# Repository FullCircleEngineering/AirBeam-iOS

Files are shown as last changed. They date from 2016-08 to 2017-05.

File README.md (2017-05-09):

# AirBeam-iOS
This directory contains material for an iOS modified AirBeam.  The build files include revisions to the Eagle PCB layout/circuitry, and revisions to the Arduino firmware code.

1. PCB files original: Airbeam-master
2. PCB files modified: Airbeam-iOS-modifications
3. Firmware files modified: AirBeamFirmware_11_14_15-iOS

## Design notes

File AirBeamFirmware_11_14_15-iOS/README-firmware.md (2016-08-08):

# AirBeam Firmware for iOS modifications

## Original source code
This firmware was modified from the original source code available from AirCastingAndroidClient/arduino/aircasting/AirBeamFirmware_11_14_15.

The original firmware was released under the GNU Affero General Public License v3.

## SDK and dependencies
This code was successfully compiled, uploaded and tested using the Arduino 1.6.5 IDE.  The hardware board equivalent for the AirBeam is the "Leonardo".  You must also copy the "DHT-sensor-library-master" folder to your IDE libary root directory to ensure proper linking with the firmware library dependencies. 

## The RN4020 BTLE module
This firmware was modified to work with the modified AirBeam hardware.  The AirBeam hardware was modified to use the RN4020 BTLE module instead of the current BlueTooth Standard (SPP) module.  The RN4020 is unique in that is does not use a standard BTLE characteristic, rather abstracts on BTLE to create a pseudo-SPP serial interface.  
In other words, you can stream ASCII characters to the RN4020 as you would a BlueTooth Standard (SPP) module, and capture those characters on the other side of your connection as if it were a serial/SPP connection.
The implications: Serial data can be streamed to the RN4020 module just as they are being done currently with the BlueTooth Standard module.  No special communication/configuration is necessary firmware side to accomodate BTLE.
  
## Modifications for iOS
No significant modifications occured for use with iOS other than changing the configuration options in the ```setup(){}``` section to configure the rn4020 using AT commands (refer to the rn4020 user guide).
**The data output has not changed** from the 11/14/15 version of the firmware, accept to stream the data as newline delimited blocks of comma delimited fields (instead of the old version of character-heavy JSON).

#TO DO
The firmware is incomplete as of 08/08/2016.  Additional code needs to be added to the ```setup(){}``` section to capture the RN4020 UID, e.g. AirBeam-04A35T67
This UID needs to be included in each data block export so that the data can be associated with a specific device/UID.

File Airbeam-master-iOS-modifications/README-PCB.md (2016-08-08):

# AirBeam-Hardware(PCB)-iOS

## Original source code
These design files were modified from the original source file available from https://github.com/vitiral/Airbeam.

## Modifications for iOS
MODIFIED: 07/08/2016 Nick Masson nicholas.b.masson@gmail.com

The original source files were modified to remove the old BlueTooth Classic module and replace it with the [RN4020 BTLE module](http://www.microchip.com/wwwproducts/en/RN4020).
The RN4020 takes a 3.3V TX/RX connection akin to the old BTClassic module.  It communicates with it's master via AT commands (reference the user guide).
Unlike other BTLE modules, it does use a standard BTLE profile for sending/receiving data.  It uses the Microchip-specific MLDP profile, which allows for a transparent serial-like connection (essentially a BTClassic connection using SPP).  As such, ASCII data can be streamed to the RN4020 over UART as with the BTClassic SPP method.

The 5-pin header wiring was also modified to remove a GPIO connection and replace it with the V_charger connection.  i.e. you can now use the 5-pin header to charge the LiPo battery with an unregulated 5VDC input (analagous to charging via the USB port).  This allows for more robust connections when integrating the AirBeam in to other control/embedded systems.

## ***IMPORTANT***

#Testing
The revised PCB was printed, populated and tested.  All BTLE functionality was verified and working.  As such, the Gerber Files included here should be verified for production.

#BOM
***NO CHANGES*** have been made to the BOM between the original and modified files directories.  The possition of all components on the board, however, is the exact same as before **accept** the RN4020 module.
The old BOM and pick'n'place possitions should be the same; the only change necessary is repalcing the BTClassic module possition with the possition of the RN4020 module.

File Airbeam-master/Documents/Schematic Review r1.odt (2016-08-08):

Todo:

- Update USB voltage regulator

Hi Fellas-

Garrett, thanks for sending the design files and opening it up to review. I just completed my review of the Rev1 Schematic. I downloaded the files from Github at 9:15a on 3/25, which according to Garrett's email yesterday is the most up to date version.

I completed the following tasks:

1. Reviewed each section of the circuit
2. Verified USB connection scheme to uC
3. Checked crystal selection
4. Checked HWB pin
5. Checked to be sure the board is a good representation of a Leonardo
6. Reviewed supervisor selection and the output polarity.
7. Reviewed switcher selection.
8. Checked capacitor choices for switchers
9. Reviewed P-ch mosfet selection
10. Checked connection to the BT module
11. Checked pinout of ICSP port
12. Checked the LiIon charger chip and Iset resistor
13. Checked sensor connections.
14. Reviewed ESD connections.
15. Reviewed dumb stuff like connections to pins, spot checked pin names, USB pinout,

Here are my suggestions for changes to make (I think you know some of them exist, but I don't want to miss them):

1. LED_BT circuit doesn't have a connection to signal or ground.

Knew about this one, has been connected to Pin 13 as confirmed by Michael.

2. The UBT schematic symbol looks like it is missing an outline. Same for the USB connector.
  Updated – also made the temp sensor and voltage regulators have an outline.
3. Many of the parts have superfluous information still visible which makes the schematic appear cluttered. Example: UBT's pin names like 'P$1' are listed. Same for Con_addon, USB's pin directions, etc...

Good point. Changed.

4. I see you've selected the SOT-23 version of the MCP73831. With 5V in and a dead battery at 2.9V the part will try to charge at 500mA which generates 1W of heat. The SOT-23 part has thermal resistance of 230*C/W, which will result in using the chip's thermal limiting feature, and significantly slow down the charge time. I would suggest changing to the DFN part which has a thermal resistance of 76*C/W, or lower if a large PCB pad is used.

Done as of revision 1_4

5. The 5V IO connections from the uC go directly to the 3.3V BT module IO pins. There needs to be level shifters at least from uC->BT to ensure there is no damage to the pin. I can suggest http://www.digikey.com/product-detail/en/SN74LVC1G125DBVR/296-11603-1-ND/385742

Thankyou and done. I used your part

6. VR_MOS-N1 is listed on the BOM as DNP but it will be needed to control the fan. Also, if the fan is always running when the unit is running is it needed at all? If so, N-channel FETs should be at a lower potential than the load. Finally, I wasn't able to review the part selection since there is no part information on the BOM (I'd suggest leaving part information in the BOM and marking DNP in another field in case you want to quickly change population status).

I will use the Value field from now on. Michael has suggested that he would appreciate this part – and the only overhead is a 0ohm resistor. I will continue with it in the design.

7. Any connection that is accessible to the customer should have ESD protection. I think the CON_ADDON will be user-accessible, so ESD protection should be added. I don't think other connections are accessible, but if they are protection should be added.

Would you recommend just a Varistor (like the Arduinio)? I have added varistors and a ferite bead onto the GND. Let me know if you think this is enough.

8. The uC crystal that you selected may have too high load capacitance. I would suggest one with 10-15pF typ of load capacitance to keep the 32u4 happy. Although if you have the BOM for the leonardo and this is the part that is listed then you should probably keep what works.

The range suggestion is 12-22pF, and I have 20pF. The Leonardo had 22pF caps. I'm using the caps that are suggested with this crystal.

I also checked the page you suggested in the email and responded – the crystal falls within the 10-22pF range specified (table 6.3, page on the uC datasheet (page 30) )

9. You need to add a pullup on the output of the VDETECT supervisor part.

NOTE: The part has changed, but both parts were push/pull. I think you may have made a mistake.

10. I've been thinking about the VDETECT voltage limit, and you may want to find a part that has a slightly higher cutoff. This would be to accommodate the wide temperature range that the battery is forced to operate under. While it will reduce the battery life of the battery, it could increase the number of useful cycles that the battery gets over time. Finding one a 3.0 or 3.1V also wouldn't represent much energy loss because that's the non-linear part of the Li_Ion discharge curve.

I could not find a part from that company on digikey. I found a different companies part. Please review:

http://www.digikey.com/product-detail/en/APX809-31SAG-7/APX809-31SAGDICT-ND/1844722

I have added the part to the schematic

And some questions that may not be problems, but I don't understand them:

1. What is the little drawing of the Arduino in the lower right hand corner of the schematic?

Answered in separate email.

2. Regarding the AREF connection question: no, it does not need to be connected to VCC since the chip has a crappy internal reference of 1/2VCC, VCC, or GND. However you're right to use the capacitor for stability of the self-selected reference.
3. Is there a reason that you're connecting the BT module to IO10 and IO11? I would think that using the hardware UART at D0 and D1 might be easier. However if that is how the current prototype is used, then I'd stick with what works.
4. You have the PS pins of the switchers connected to ground. While this increases efficiency at low load, it also drastically increases the supply ripple in this low power state. Because some of the sensors depend on this voltage rail for accuracy, will this ripple voltage mess up the error budget? At the very least, it is probably a good idea to have a couple 0-ohm jumpers to enable you to change this setting with a population change.

I have added 0 ohm jumpers and selected the 5V switcher to do continuous switching (PS = 1) and the 3.3V to be in power save (PS = 0).

5. How did you determine acceptable ripple of the switcher output for capacitor selection? Since the sensors depend on the 5V regulator for accuracy it is important.

I used the suggested schematic. I rechecked the values, and the calculated max delta V = 0.01 Volts. I also checked it for over 10x our current usage (1A, which isn't even possible for this device), and it is still only .02 Volts. I'd say 20uF is good. This was at a Vmin = 2.9 (higher Vmin only helps us). It is in BOM/Calculations.ods.

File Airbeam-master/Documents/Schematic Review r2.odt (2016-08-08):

Hi Garrett-

Nice layout. Glad that you were able to stick with a 2-layer, 1-sided board. I've completed the review. Below are my notes. Feel free to reach out with any questions or comments, which I'm sure you'll have since many of the PCB layout design decisions are often subjective.

Aspects Reviewed:

1. Reviewed changes suggested from my schematic review.
2. Reviewed the new supervisor circuit
3. Reviewed the new ESD protection
4. Switcher layouts for noise
5. Switcher layouts for heat
6. USB charger for heat, noise
7. Position of Bluetooth module WRT to other components and pours
8. Crystal position
9. Decoupling capacitor positions
10. High current trace widths and return paths
11. Ground design of analog vs. digital vs. power
12. Clearance from PCB edge
13. Reviewed silkscreen: off pads, sufficient size, clarity, polarization marks, pin 1 marks
14. Reviewed soldermask:
15. Reviewed solderpaste
16. Feducial review
17. Run DRC per Laen's specs

Suggestions for changes to make:

1. For U$2, there is not reference designator on the schematic.

Done. I have renamed it to U_VRUSB

2. For U$2, I would suggest using a different copper pour that does not have thermals. This will increase the effectiveness of the thermal pad. Also, I believe that you need a 1sqin copper pour to act as a heatsink in order to reach the thermal resistance listed on the datasheet. I would suggest moving this entire circuit to the right to better take advantage of the available pour, and perhaps move a few traces around to facilitate heat expulsion.

Done. It should be good now!

3. I would flip the position of U-C1 and C2 to place the smaller cap closer to the part.

Done

4. I would move UR_R2 on the PCB to allow better heat conduction of the pour away from the part. Rotating UR_C1 would be helpful.

Done. Also, caps were rotated.

5. The trace going from Vout to VR3_R1 should connect to the output node further away from the switcher than the output capacitors for stability. Rerouting this trace will also allows you to more directly connect the ground pins of the output capacitors to the ground plane (a must), and increase the size of the thermal pad for the part (not really needed since the power consumption of this part is low).

I moved it to increase pad area and it is now coming out at the pad of the cap. This is going to have to be good enough.

6. The via coming off of VR3_R1 on the 3.3V side goes nowhere and should be removed.

Removed, thanks for noticing.

7. on U_VR3 and U_VR5 I think pins 7 and 9 are flipped on your footprint. Pin 7 should be PS, 9 should be GND.

Oh my god, I had the pin numbers totally flipped on the right side. Updated, with that whole section re-designed around the new pins and your suggestions.

8. You seem to have a couple vias going nowhere at (35,25) and (35, 28)

Thanks, they were meant to be GND vias, but then the Voltage bus went under them.

9. VR5_C2 and C3 need to have their ground traces connect directly to U_VR5's ground pin. I would suggest moving the +5V trace that is blocking it around the back side of the capacitors, which is should do anyway to give the smoothest output.

Yes, I suppose connecting directly to the GND is best. Done.

10. All copper traces and pours should be kept away from the area of the BT module that has the antenna to prevent signal attenuation. I would pull back the pours as much as possible, but at least back to where the SMT pins of the parts are and as far down the board as possible. See page 25 of the BT module datasheet.

Absolutely. I looked at the data sheet and created a 15mm restrict area (per their design). Thanks for catching this.

11. I'm not sure if it is possible, but UC_C1 and C2 should be moved closer to the uC. Decoupling capacitors are more effective when their output doesn't have to flow through 2 vias. I would rate this as non-critical.

I moved one of the caps (to a different Vin pin I hadn't seen before) and altered the design as you suggested.

12. I would add a decoupling cap to the U_BT_RX part. Also, those level shifters don't have their reference designators visible on the schematic.

The RX component already shared a 1uF cap with the BT module itself. However, I added a 100nF cap to the TX part (5V). Added reference designators.

13. I would add decoupling capacitors on all sensor power pins, including the CON_ADDON connector.

Done. I skipped the 3.3V because there is no room and it is right next to the power supply (and therefore 20uF of caps).

14. Silkscreen problems:

General comment: silkscreen on the pads is because these parts/pads are from libraries. I have used them for a long time and they have always worked well. I don't know why they put SS on the pads, but it works.

  1. R_LED_CH (no polarity, overlap on other silk)

It is a resistor, silkscreen is intended.

  1. U_FB2

silkscreen intended.

  1. U_FB1 (name not there, some silk on the pad)

fixed the name, silkscreen intended

  1. U_VR5
  1. I don't think you have pin1 indicators on any of the ICs. Please add them and be sure that they are visible after the part has been populated.

I added pin indicators for all parts. Thanks.

  1. Vdetect has silk on the pads

These are on purpose.

  1. FAN_MOS_N1, VR_MOS-P1, CON_FAN, BT module, UC_F1, U_VR3, V_VR5, CONN_ADDON has silk on the pads

This has never been a big deal for me (and is actually designed in on purpose for the resistors, capacitors, mosfets, and ferrite beads).

  1. CON_ADDON has no silk name

fixed

Questions and comments that may not be problems:

1. Regarding the ESD protection, I think Varistors selected are sufficient.

Good, thanks for reviewing.

2. There are a few vias that appear to be randomly placed throughout that I don't understand. (4,32), (6, 27), (12, 30) (54, 5). Are they there to connect the two planes? If so, this should be done with 1 via, or if multiple are needed then they should be closer together to prevent ground loops.

I have read a large number of accounts that say that by throwing Vias all over the place (at random places) you will prevent ground loops. That is the intent here. I actually added even more vias to the GND plane in various spots.

3. Be mindful of the ground return path for things, especially high current and switched current paths. It looks ok for now but a 2-layer one sided design is susceptible to having ridiculous ground paths which generate noise and measurement anomalies.

Thanks, will do. I think the fan and the Dust sensor are definitely the most suceptible to this. What would you do? I assume caps are the best defense.

4. It seems that there are many TH components. I'm not sure if that is a design decision, but it'll cost more to manufacture TH components.

It was a design decision made by Michael and Chris – and I actually forgot the major price difference for TH. Most of them were chosen because they have better structural reliability, but the connectors to the fan and dust sensor could have definitely been SMT.

5. Did you include the Mask and Silk layers when running DRC? I think you may have found a bunch of the above errors.

I ignored the silkscreen error checking, so I forgot to check the values layer. This time I went through it step by step and approved them.

Next Steps:

1. Once you generate the gerbers, please send them over to me to review them on the most basic level.

They are included in the folder “Gerber”

2. I did not review the mechanical aspects of the design. Perhaps Chris would be better suited for that thanks to the use of DXFs?

Yes, I think so.

3. With the board complete, don't forget to create a paper printout and double check footprints. I would include things like mounting hardware in this review.There is a weird setting in Eagle to do this. Instructions: http://bit.ly/1gVq6sA

I have printed this out as Airbeamv0_01.pdf

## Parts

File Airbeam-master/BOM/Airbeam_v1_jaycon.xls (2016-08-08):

Qty-1 | Part References | Value | Package | Mfg Part Num | Mfg Name | Description | Value | Pkg Code | VID | Vendor Part Num | Price @20 | Price @ 500 | Height | Link | XREF
1 | VR_R4 | 0 | 0603-RES | RC0603JR-070RL | Yageo | Resistor | 0 | 603 | * | 311-0.0GRCT-ND | 0.0045 | 0.00294 | * | http://www.digikey.com/product-detail/en/RC0603JR-070RL/311-0.0GRCT-ND/729622 | REF51
2 | VR3_0R1, VR5_0R2 | 0 | 0603-RES | RC0603JR-070RL | Yageo | Resistor | 0 | 603 | * | 311-0.0GRCT-ND | 0.0045 | 0.00294 | * | http://www.digikey.com/product-detail/en/RC0603JR-070RL/311-0.0GRCT-ND/729622 | REF51
2 | R_LED_BT, R_LED_CH | 1.4k | 0603-RES | RC0603FR-071K4L | Yageo | Resistor | 1.4k | 603 | * | 311-1.40KHRCT-ND | 0.0108 | 0.00364 | * | http://www.digikey.com/product-detail/en/RC0603FR-071K4L/311-1.40KHRCT-ND/729808 | REF53
1 | UC_R1 | 1M | 0603-RES | RC0603FR-071ML | Yageo | Resistor | 1M | 603 | * | 311-1.00MHRCT-ND | 0.015 | 0.00364 | * | http://www.digikey.com/product-detail/en/RC0603FR-071ML/311-1.00MHRCT-ND/729791 | REF60
7 | BT_C1, CD_C1, CE_C1, CTH_C1, UC_C5, UC_C7, UC_C8 | 1uF | 0603-CAP | C1608X5R1C105K080AA | TDK | Capacitor | 1uF | 603 | * | 445-1416-1-ND | 0.0337 | 0.02356 | * | http://www.digikey.com/product-detail/en/C1608X5R1C105K080AA/445-1416-1-ND/569082 | REF46
1 | VR3_L1 | 2.2uH | 1210 | BRL3225T2R2M | Taiyo Yuden | Inductor 2.2uH | 2.2uH | 1210 | * | 587-2165-1-ND | 0.196 | 0.13476 | * | http://www.digikey.com/product-detail/en/BRL3225T2R2M/587-2165-1-ND/2002863 | REF29
1 | VR5_L1 | 4.7uH | 1210 | CBC3225T4R7MR | Richtek USA | Voltage Reg Buck-Boost | * | * | * | 1028-1260-1-ND | 0.8388 | 0.57076 | * | http://www.digikey.com/product-detail/en/RT6150BGQW/1028-1260-1-ND/4733184 | REF26
1 | UC_NTC | 10k | 402 | ERT-J0EM103J | Panasonic | Thermister ? NTC | 10k | 603 | * | P12985CT-ND | 0.143 | 0.07 | * | http://www.digikey.com/product-detail/en/ERT-J0EM103J/P12985CT-ND/761196 | REF41
4 | CTH_R1, UC_R2, UC_R4, UC_R6 | 10k | 0603-RES | RC0603JR-0710KL | Yageo | Resistor | 10k | 603 | * | 311-10KGRCT-ND | 0.008 | 0.00364 | * | http://www.digikey.com/product-detail/en/RC0603JR-0710KL/311-10KGRCT-ND/729647 | REF56
8 | UR_C1, UR_C2, VR3_C1, VR3_C2, VR3_C3, VR5_C1, VR5_C2, VR5_C3 | 10uF | 805 | C2012X5R1C106K085AC | TDK | Capacitor | 10uF | 805 | * | 445-7644-1-ND | 0.1102 | 0.07298 | * | http://www.digikey.com/product-detail/en/C2012X5R1C106K085AC/445-7644-1-ND/2733716 | REF47
1 | U_C3 | 10uF/50V | 1206 | CL31A106KBHNNNE | Samsung | Capacitor ? 50V | 10uF / 50V | 1206 | * | 1276-2876-1-ND | 0.332 | 0.12082 | * | http://www.digikey.com/product-detail/en/CL31A106KBHNNNE/1276-2876-1-ND/3890962 | REF48
1 | UC_CRYSTAL | 16MHz | HC49UP | ECS-160-20-3X-TR | ECS | Crystal | 16MHz | * | * | XC1776CT-ND | 0.455 | 0.266 | 2.3 | http://www.digikey.com/product-detail/en/ECS-160-20-3X-TR/XC1776CT-ND/2676640 | REF5
2 | UC_C3, UC_C4 | 20pF | 0603-CAP | CL10C200JB8NNNC | Samsung | Capacitor | 20pF | 603 | * | 1276-1187-1-ND | 0.0212 | 0.00966 | * | http://www.digikey.com/product-detail/en/CL10C200JB8NNNC/1276-1187-1-ND/3889273 | REF43
2 | U_R1, U_R2 | 22 | 0603-RES | RC0603JR-0722RL | Yageo | Resistor | 22 | 603 | * | 311-22GRCT-ND | 0.008 | 0.00278 | * | http://www.digikey.com/product-detail/en/RC0603JR-0722RL/311-22GRCT-ND/729690 | REF52
1 | VR5_R2 | 53.6k | 0603-RES | RC0805FR-0753K6L | Yageo | Resistor | 53.6k | 603 | * | 311-53.6KCRCT-ND | 0.021 | 0.00364 | * | http://www.digikey.com/product-detail/en/RC0805FR-0753K6L/311-53.6KCRCT-ND/730972 | REF57
3 | VR3_R2, VR3_R4, VR3_R5 | 86.6k | 0603-RES | ERJ-3EKF8662V | Panasonic | Resistor | 86.6k | 603 | * | P86.6KHCT-ND | 0.015 | 0.00624 | * | http://www.digikey.com/product-detail/en/ERJ-3EKF8662V/P86.6KHCT-ND/198534 | REF58
2 | UC_C1, UC_C2 | 100n | 0603-CAP | C1608X7R1E104K080AA | TDK | Capacitor | 100nF | 603 | * | 445-1316-1-ND | 0.011 | 0.0077 | * | http://www.digikey.com/product-detail/en/C1608X7R1E104K080AA/445-1316-1-ND/567697 | REF44
4 | BT_C2, UC_C6, U_C1, VR5_C4 | 100nF | 0603-CAP | C1608X7R1E104K080AA | TDK | Capacitor | 100nF | 603 | * | 445-1316-1-ND | 0.011 | 0.0077 | * | http://www.digikey.com/product-detail/en/C1608X7R1E104K080AA/445-1316-1-ND/567697 | REF44
1 | U_C4 | 100nF | 0603-CAP | CC0603ZRY5V9BB104 | Yageo | Capacitor ? 50V | 100nF / 50V | 603 | * | 311-1343-1-ND | 0.017 | 0.00546 | * | http://www.digikey.com/product-detail/en/CC0603ZRY5V9BB104/311-1343-1-ND/2103127 | REF45
3 | VR3_R1, VR5_R1, VR_R2 | 487k | 0603-RES | ERJ-3EKF4873V | Panasonic | Resistor | 487k | 603 | * | P487KHCT-ND | 0.015 | 0.00624 | * | http://www.digikey.com/product-detail/en/ERJ-3EKF4873V/P487KHCT-ND/198411 | REF59
1 | ATMEGA32U4-T | DNP | TQFP44-PAD | ATMEGA32U4-AU | Atmel | Microcontroller | DNP | * | * | 556-ATMEGA32U4-AU | * | 3.51 | * | http://www.mouser.com/ProductDetail/Atmel/ATMEGA32U4-AU/?qs=sGAEpiMZZMvAvBNgSS9Lqh1wBIpnYT9c | REF1
1 | UBT | BT-NVC-MDCS42A | BT_NVC-MDCS42A | NVC-MDCS42A | iNova | BT Module | * | * | * | n/a | 0 | * | * | n/a | REF8
6 | U_Z1, U_Z2, U_Z3, U_Z4, U_Z5, U_Z6 | CG0603MLC-05E | CT/CN0603 | CG0603MLC-05E | Bourns Inc. | Varistor | * | * | * | CG0603MLC-05ECT-ND | 0.1472 | 0.1092 | * | http://www.digikey.com/product-detail/en/CG0603MLC-05E/CG0603MLC-05ECT-ND/3438061 | REF39
1 | CON_BAT | CON_BAT | JST-2-SMD | S2B-PH-SM4-TB(LF)(SN) | JST Sales America | Conn Battery | * | * | * | 455-1749-1-ND | 0.521 | 0.34734 | * | http://www.digikey.com/product-detail/en/S2B-PH-SM4-TB(LF)(SN)/455-1749-1-ND/926846 | REF25
1 | CON_DUST | CON_DUST | S4B-EH | S4B-EH | JST Sales America | Connector (Dust Sensor) | * | * | * | 455-1627-ND | 0.169 | 0.09906 | * | http://www.digikey.com/product-detail/en/S4B-EH(LF)(SN)/455-1627-ND/926535 | REF17
1 | U_MEGA32U-Q | ATMEGA32U4-MU | QFN44ML7X7 | ATMEGA32U4-MU | Atmel | Microcontroller | 16MHz | * | * | ATMEGA32U4RC-MU-ND | 5.741 | 3.95492 | * | http://www.digikey.com/product-search/en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 | REF2
1 | U_FANM | DNP | SOT23 | NDS331N | Fairchild | MOSFET ? N | * | * | * | NDS331NCT-ND | 0.362 | 0.1407 | * | http://www.digikey.com/product-detail/en/NDS331N/NDS331NCT-ND/458997 | REF62
3 | UC_R3, VR3_0R2, VR5_0R1 | DNP | 0603-RES | RC0603JR-070RL | Yageo | Resistor | 0 | 603 | * | 311-0.0GRCT-ND | 0.0045 | 0.00294 | * | http://www.digikey.com/product-detail/en/RC0603JR-070RL/311-0.0GRCT-ND/729622 | REF51
1 | VR_C1 | DNP | 2917_CAP | T491D107K010AT | Kernet | Capacitor ? Tantilum | 100uF | 2917 | * | * | * | * | * | http://www.digikey.com/product-detail/en/T491D107K010AT/399-3769-1-ND/819094 | REF49
1 | RESET_SWITCH | DNP | SWITCH_TACTILE | TL3315NF250Q | E-Switch | Switch | * | * | * | EG4622CT-ND | 0.185 | 0.14674 | * | http://www.digikey.com/product-detail/en/TL3315NF250Q/EG4622CT-ND/1870402 | REF3
4 | CA_FB1, U_FB1, U_FB2, U_FB3 | FERITE_BEAD | U_FB1 | MH2029-600Y | Bourns Inc. | Ferite Bead | 3A | * | * | MH2029-600YCT-ND | 0.0476 | 0.02324 | * | http://www.digikey.com/scripts/DkSearch/dksus.dll?Detail&itemSeq=147728399&uq=635324759172303876 | REF38
3 | FID1, FID2, FID3 | FIDUCIALMOUNT | FIDUCIA-MOUNT | DNP | DO NOT POPULATE | DO NOT POPULATE | * | * | * | * | * | * | * | DO NOT POPULATE | REF63
1 | CON_ICSP | ICSP | 2X03 | 67997-206HLF | FCI | Connector ISP | * | * | * | 609-3234-ND | 0.292 | 0.17494 | * | http://www.digikey.com/product-detail/en/67997-206HLF/609-3234-ND/1878491 | REF4
1 | LED_BT | LED | LED_550 | 550-1107F | Dialight | LED - Red | Red | * | * | 350-1620-ND | 0.995 | 0.5202 | * | http://www.digikey.com/product-detail/en/550-1107F/350-1620-ND/809018 | REF7
1 | LED_CH | LED | LED_550 | 550-1307F | Dialight | LED ? Green | Green | * | * | 350-1627-ND | 1.09 | 0.5712 | * | http://www.digikey.com/product-detail/en/550-1307F/350-1627-ND/809025 | REF6
1 | LION_BATTERY | OFF_BOARD | EMPTY | 585460_2000MAH | UnionFortune | Battery ? Lion | 2000mAh | * | * | * | 12.55 | 11.16 | * | http://www.jayconsystems.com/3-7-volt-rechargeable-lithium-battery-2000-mah.html | REF24
1 | 3_3V_FAN_COPOL | OFF_BOARD | EMPTY | F16FB-05LLC/E | Copol | Fan Copol | * | * | * | 563-1106-ND | 10.11 | 6.46552 | * | http://www.digikey.com/product-detail/en/F16EA-03LLC%20%2FE/563-1106-ND/1165500 | REF13
1 | DUST_SENSOR | OFF_BOARD | EMPTY | PPD60PV-T2 | SHINYEI | Sensor Dust | * | * | * | * | 0 | 25 | * | n/a | REF12
1 | U_PUSHB | PUSHBUTTON | PUSHBUTTON | LC2259EENP | E-Switch | Power Button | * | * | * | * | 0.655 | 0.535 | * | http://www.futureelectronics.com/en/Technologies/Product.aspx?ProductID=LC2259EENPESWITCH6265227&IM=0 | REF23
1 | U_TEMP-HUM | RHT03 | RHT03 | RHT03 | Maxdetect | Sensor Temp-Humidity | * | * | * | * | 8.96 | 7.96 | * | https://www.sparkfun.com/products/10167 | REF11
1 | CON_FAN | SUR_2PIN | JST-0.8MM | SM02B-SURS-TF | SUR | Connector Fan | 2 pin | * | * | 455-2039-1-ND | 0.581 | 0.4066 | * | http://www.digikey.com/product-detail/en/SM02B-SURS-TF(LF)(SN)%3B/455-2039-1-ND/1634927 | REF15
1 | CON_EXTERN | TBLOCK_5 | TBLOCK_5 | 1770911 | Phoenix | Connector (addon board) | 5 pin | * | DK | 277-2082-1-ND | 0.869 | 0.77 | * | http://www.digikey.com/product-detail/en/1770911/277-2082-1-ND/2192492 | REF19
1 | U_USB_CH | USB-BATTERY_LOAD | TDFN33-14 | AAT3672IWO-4.2-1-T1 | Skyworks Solutions | USB ? Battery + Load | 4.2V | * | * | 863-1545-1-ND | 1.06 | 0.88 | * | http://www.digikey.com/product-detail/en/AAT3672IWO-4.2-1-T1/863-1545-1-ND/4753079 | REF28
1 | CON_USB | USB-FCI | USB-FCI | 10103594-0001LF | FCI | Connector USB Micro | * | * | * | 609-4050-1-ND | 0.678 | 0.45232 | * | http://www.digikey.com/product-detail/en/10103594-0001LF/609-4050-1-ND/2350357 | REF21
2 | U_VR3, U_VR5 | VREG-RTEC6150 | WFDFN-10 | RT6150BGQW | Richtek USA | Voltage Reg Buck-Boost | * | * | * | 1028-1260-1-ND | 0.8388 | 0.57076 | * | http://www.digikey.com/product-detail/en/RT6150BGQW/1028-1260-1-ND/4733184 | REF26
2 | U_BT_RX, U_BT_TX | V_BUFFER | SOT23-5 | SN74LVC1G125DBVR | Texas Instruments | Voltage Buffer | <5 | SOT23-5 | * | 296-11603-1-ND | 0.266 | 0.1482 | * | http://www.digikey.com/product-detail/en/SN74LVC1G125DBVR/296-11603-1-ND/385742 | REF9

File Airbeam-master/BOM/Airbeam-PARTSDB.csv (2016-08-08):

Mfg Part Num | Mfg Name | Description | Value | Pkg Code | VID | Vendor Part Num | Price @20 | Price @ 500 | Height | Link
ATMEGA32U4-AU | Atmel | Microcontroller | 16MHz |  |  | 556-ATMEGA32U4-AU |  | 3.51 |  | http://www.mouser.com/ProductDetail/Atmel/ATMEGA32U4-AU/?qs=sGAEpiMZZMvAvBNgSS9Lqh1wBIpnYT9c
ATMEGA32U4-MU | Atmel | Microcontroller | 16MHz |  |  | ATMEGA32U4RC-MU-ND | 5.741 | 3.95492 |  | http://www.digikey.com/product-search/en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
TL3315NF250Q | E-Switch | Switch |  |  |  | EG4622CT-ND | 0.185 | 0.14674 |  | http://www.digikey.com/product-detail/en/TL3315NF250Q/EG4622CT-ND/1870402
67997-206HLF | FCI | Connector ISP |  |  |  | 609-3234-ND | 0.292 | 0.17494 |  | http://www.digikey.com/product-detail/en/67997-206HLF/609-3234-ND/1878491
ECS-160-20-3X-TR | ECS | Crystal | 16MHz |  |  | XC1776CT-ND | 0.455 | 0.266 | 2.3 | http://www.digikey.com/product-detail/en/ECS-160-20-3X-TR/XC1776CT-ND/2676640
550-1307F | Dialight | LED – Green | Green |  |  | 350-1627-ND | 1.09 | 0.5712 |  | http://www.digikey.com/product-detail/en/550-1307F/350-1627-ND/809025
550-1107F | Dialight | LED - Red | Red |  |  | 350-1620-ND | 0.995 | 0.5202 |  | http://www.digikey.com/product-detail/en/550-1107F/350-1620-ND/809018
NVC-MDCS42A | iNova | BT Module |  |  |  | n/a | 0 |  |  | n/a
SN74LVC1G125DBVR | Texas Instruments | Voltage Buffer | <5 | SOT23-5 |  | 296-11603-1-ND | 0.266 | 0.1482 |  | http://www.digikey.com/product-detail/en/SN74LVC1G125DBVR/296-11603-1-ND/385742
RHT03 | Maxdetect | Sensor Temp-Humidity |  |  |  |  | 6.55 | 6.55 |  | http://www.ebay.com/itm/NEW-DHT22-AM2302-Digital-Temperature-Humidity-Sensor-Replace-SHT11-SHT15-Logger-/271175728425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
PPD60PV-T2 | SHINYEI | Sensor Dust |  |  |  |  | 0 | 25 |  | n/a
F16FB-05LLC/E | Copol | Fan Copol |  |  |  | 563-1106-ND | 10.11 | 6.46552 |  | http://www.digikey.com/product-detail/en/F16EA-03LLC%20%2FE/563-1106-ND/1165500
22-05-7025 | Molex | Connector Fan | 2 pin |  |  | 538-22-05-7025 |  | 0.347 |  | http://www.mouser.com/ProductDetail/Molex/22-05-7025/?qs=xrDmMQn67Z5jplgrvRQ%20IpQ==
SM02B-SURS-TF | SUR | Connector Fan | 2 pin |  |  | 455-2039-1-ND | 0.581 | 0.4066 |  | http://www.digikey.com/product-detail/en/SM02B-SURS-TF(LF)(SN)%3B/455-2039-1-ND/1634927
02SUR-32S | JST Sales America | Connector Fan (wire) |  |  |  | 455-2176-ND | 0.481 |  |  | http://www.digikey.com/scripts/DkSearch/dksus.dll?Detail&itemSeq=147727180&uq=635324752046867637
S4B-EH | JST Sales America | Connector (Dust Sensor) |  |  |  | 455-1627-ND | 0.169 | 0.09906 |  | http://www.digikey.com/product-detail/en/S4B-EH(LF)(SN)/455-1627-ND/926535
1770911 | Phoenix | Connector (addon board) | 5 pin |  | DK | 277-2082-1-ND | 0.869 | 0.77 |  | http://www.digikey.com/product-search/en?x=0&y=0&lang=en&site=us&KeyWords=3M9368-ND
10103594-0001LF | FCI | Connector USB Micro |  |  |  | 609-4050-1-ND | 0.678 | 0.45232 |  | http://www.digikey.com/product-detail/en/10103594-0001LF/609-4050-1-ND/2350357
AP2161DM8G-13 | Diodes Incorporated | USB Overcurrent protection |  | 8-TSSOP, 8-MSOP |  | AP2161DM8G-13DICT-ND |  | 0.2413 |  | http://www.digikey.com/product-detail/en/AP2161DM8G-13/AP2161DM8G-13DICT-ND/3720121
LC2259EENP | E-Switch | Power Button |  |  |  |  | 0.655 | 0.535 |  | http://www.futureelectronics.com/en/Technologies/Product.aspx?ProductID=LC2259EENPESWITCH6265227&IM=0
585460_2000MAH | UnionFortune | Battery – Lion | 2000mAh |  |  |  | 12.55 | 11.16 |  | http://www.jayconsystems.com/3-7-volt-rechargeable-lithium-battery-2000-mah.html
S2B-PH-SM4-TB(LF)(SN) | JST Sales America | Conn Battery |  |  |  | 455-1749-1-ND | 0.521 | 0.34734 |  | http://www.digikey.com/product-detail/en/S2B-PH-SM4-TB(LF)(SN)/455-1749-1-ND/926846
RT6150BGQW | Richtek USA | Voltage Reg Buck-Boost |  |  |  | 1028-1260-1-ND | 0.8388 | 0.57076 |  | http://www.digikey.com/product-detail/en/RT6150BGQW/1028-1260-1-ND/4733184
MC34673AEPR2 | Freescale Semiconductor | Voltage Reg USB |  |  |  | MC34673AEPR2CT-ND |  | 0.7 |  | http://www.digikey.com/product-detail/en/MC34673AEPR2/MC34673AEPR2CT-ND/1867915
AAT3672IWO-4.2-1-T1 | Skyworks Solutions | USB – Battery + Load | 4.2V |  |  | 863-1545-1-ND | 1.06 | 0.88 |  | http://www.digikey.com/product-detail/en/AAT3672IWO-4.2-1-T1/863-1545-1-ND/4753079
BRL3225T2R2M | Taiyo Yuden | Inductor 2.2uH | 2.2uH | 1210 |  | 587-2165-1-ND | 0.196 | 0.13476 |  | http://www.digikey.com/product-detail/en/BRL3225T2R2M/587-2165-1-ND/2002863
CBC3225T4R7MR | Taiyo Yuden | Inductor 4.7uH | 6uH | 1210 |  | 587-1624-1-ND | 0.212 | 0.12 |  | http://www.digikey.com/product-detail/en/CBC3225T4R7MR/587-1624-1-ND/1008239
RT9819C-26GV | Richtek | Low Voltage Detect | 2.9V |  |  | 1028-1023-1-ND |  | 0.15412 |  | http://www.digikey.com/product-detail/en/RT9819C-29GV/1028-1023-1-ND/2470082
APX809-31SAG-7 | Diodes Incorporated | Low Voltage Detect | 3.08V |  |  | APX809-31SAGDICT-ND |  | 0.1482 |  | http://www.digikey.com/product-detail/en/APX809-31SAG-7/APX809-31SAGDICT-ND/1844722
0ZCJ0100FF2E | Bel Fuse Inc. | Fuse Resetable | 1A |  |  | 507-1806-1-ND |  | 0.09922 |  | http://www.digikey.com/product-detail/en/0ZCJ0100FF2E/507-1806-1-ND/4156243
CD0603-Z3V9 | Bourns Inc. | Zener Vth | 3.9V |  |  | CD0603-Z3V9CT-ND |  |  |  | http://www.digikey.com/product-detail/en/CD0603-Z3V9/CD0603-Z3V9CT-ND/3534233
IRLML2246TRPBF | International Rectifier | MOSFET–P |  |  |  | IRLML2246TRPBFCT-ND |  | 0.128 |  | http://www.digikey.com/product-detail/en/IRLML2246TRPBF/IRLML2246TRPBFCT-ND/2639576
B130LAW-7-F | Diodes Incorporated | Diode Schottkey |  |  |  | B130LAW-FDICT-ND |  | 0.16128 |  | http://www.digikey.com/product-detail/en/B130LAW-7-F/B130LAW-FDICT-ND/725052
MH2029-600Y | Bourns Inc. | Ferite Bead | 3A |  |  | MH2029-600YCT-ND | 0.0476 | 0.02324 |  | http://www.digikey.com/scripts/DkSearch/dksus.dll?Detail&itemSeq=147728399&uq=635324759172303876
CG0603MLC-05E | Bourns Inc. | Varistor |  |  |  | CG0603MLC-05ECT-ND | 0.1472 | 0.1092 |  | http://www.digikey.com/product-detail/en/CG0603MLC-05E/CG0603MLC-05ECT-ND/3438061
ERT-J0EM103J | Panasonic | Thermister – NTC | 10k | 0603 |  | P12985CT-ND | 0.143 | 0.07 |  | http://www.digikey.com/product-detail/en/ERT-J0EM103J/P12985CT-ND/761196
CL10C200JB8NNNC | Samsung | Capacitor | 20pF | 0603 |  | 1276-1187-1-ND | 0.0212 | 0.00966 |  | http://www.digikey.com/product-detail/en/CL10C200JB8NNNC/1276-1187-1-ND/3889273
C1608X7R1E104K080AA | TDK | Capacitor | 100nF | 0603 |  | 445-1316-1-ND | 0.011 | 0.0077 |  | http://www.digikey.com/product-detail/en/C1608X7R1E104K080AA/445-1316-1-ND/567697
CC0603ZRY5V9BB104 | Yageo | Capacitor – 50V | 100nF / 50V | 0603 |  | 311-1343-1-ND | 0.017 | 0.00546 |  | http://www.digikey.com/product-detail/en/CC0603ZRY5V9BB104/311-1343-1-ND/2103127
C1608X5R1C105K080AA | TDK | Capacitor | 1uF | 0603 |  | 445-1416-1-ND | 0.0337 | 0.02356 |  | http://www.digikey.com/product-detail/en/C1608X5R1C105K080AA/445-1416-1-ND/569082
C2012X5R1C106K085AC | TDK | Capacitor | 10uF | 0805 |  | 445-7644-1-ND | 0.1102 | 0.07298 |  | http://www.digikey.com/product-detail/en/C2012X5R1C106K085AC/445-7644-1-ND/2733716
CL31A106KBHNNNE | Samsung | Capacitor – 50V | 10uF / 50V | 1206 |  | 1276-2876-1-ND | 0.332 | 0.12082 |  | http://www.digikey.com/product-detail/en/CL31A106KBHNNNE/1276-2876-1-ND/3890962
T491D107K010AT | Kernet | Capacitor – Tantilum | 100uF | 2917 |  |  |  |  |  | http://www.digikey.com/product-detail/en/T491D107K010AT/399-3769-1-ND/819094
RC0603JR-070RL | Yageo | Resistor | 0 | 0603 |  | 311-0.0GRCT-ND | 0.0045 | 0.00294 |  | http://www.digikey.com/product-detail/en/RC0603JR-070RL/311-0.0GRCT-ND/729622
RC0603JR-0722RL | Yageo | Resistor | 22 | 0603 |  | 311-22GRCT-ND | 0.008 | 0.00278 |  | http://www.digikey.com/product-detail/en/RC0603JR-0722RL/311-22GRCT-ND/729690
RC0603FR-071K4L | Yageo | Resistor | 1.4k | 0603 |  | 311-1.40KHRCT-ND | 0.0108 | 0.00364 |  | http://www.digikey.com/product-detail/en/RC0603FR-071K4L/311-1.40KHRCT-ND/729808
RC0603FR-072KL | Yageo | Resistor | 2k | 0603 |  | 311-2.00KHRCT-ND |  | 0.00364 |  | http://www.digikey.com/product-detail/en/RC0603FR-072KL/311-2.00KHRCT-ND/729956
RC0603FR-076K65L | Yageo | Resistor | 6.65k | 0603 |  | 311-6.65KHRCT-ND |  | 0.00364 |  | http://www.digikey.com/product-detail/en/RC0603FR-076K65L/311-6.65KHRCT-ND/730269
RC0603JR-0710KL | Yageo | Resistor | 10k | 0603 |  | 311-10KGRCT-ND | 0.008 | 0.00364 |  | http://www.digikey.com/product-detail/en/RC0603JR-0710KL/311-10KGRCT-ND/729647
RC0805FR-0753K6L | Yageo | Resistor | 53.6k | 0603 |  | 311-53.6KCRCT-ND | 0.021 | 0.00364 |  | http://www.digikey.com/product-detail/en/RC0805FR-0753K6L/311-53.6KCRCT-ND/730972
ERJ-3EKF8662V | Panasonic | Resistor | 86.6k | 0603 |  | P86.6KHCT-ND | 0.015 | 0.00624 |  | http://www.digikey.com/product-detail/en/ERJ-3EKF8662V/P86.6KHCT-ND/198534
ERJ-3EKF4873V | Panasonic | Resistor | 487k | 0603 |  | P487KHCT-ND | 0.015 | 0.00624 |  | http://www.digikey.com/product-detail/en/ERJ-3EKF4873V/P487KHCT-ND/198411
RC0603FR-071ML | Yageo | Resistor | 1M | 0603 |  | 311-1.00MHRCT-ND | 0.015 | 0.00364 |  | http://www.digikey.com/product-detail/en/RC0603FR-071ML/311-1.00MHRCT-ND/729791
NDS331N | Fairchild | MOSFET – N |  |  |  | NDS331NCT-ND | 0.362 | 0.1407 |  | http://www.digikey.com/product-detail/en/NDS331N/NDS331NCT-ND/458997
DNP | DO NOT POPULATE | DO NOT POPULATE |  |  |  |  |  |  |  | DO NOT POPULATE
Mechanical Parts
enc-bot | Quickparts | Enclosure-bottom | black STL |  |  |  |  | 225 |  | TBD
enc-top | Quickparts | Enclosure-top | black STL |  |  |  |  | 225 |  | TBD
enc-sw | Quickparts | switch cap | black STL |  |  |  |  | 75 |  | TBD
enc-bf | Quickparts | fan baffle | black STL |  |  |  |  | 75 |  | TBD
91772A145 | McMaster | enclosure screw | zinc plated steel |  |  |  |  | 0.05
99461A310 | McMaster | PCB/fan screw | zinc plated steel |  |  |  |  | 0.41 |  | http://www.fastenal.com
99461A409 | McMaster | Dust sensor screw | zinc plated steel |  |  |  |  | 0.44 |  | http://www.fastenal.com
90295A400 | McMaster | Dust sensor washer | PE |  |  |  |  | 0.06
93365A132 | McMaster | long insert | brass |  |  |  |  | 0.16
93365A130 | McMaster | short insert | brass |  |  |  |  | 0.13
93505A151 | McMaster | standoff | aluminum |  |  |  |  | 3 |  | http://www.fastenersuperstore.com

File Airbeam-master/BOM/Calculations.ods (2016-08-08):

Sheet: Load Current
Name | Value | Height (mm) | Op Voltage | Min Current (mA) | Expected Average Current (mA) | Max Current (mA) | Min Power (mW) | Expected Power (mW) | Max Power (mW) | Min mA from Bat | Exp mA from Bat | Max mA from Bat | Exp Abs Max mA from Bat | Abs Max mA from Bat | Power Comments
Microcontroller | 16MHz |  | 5 | 0.011
LED – Green |  |  | 5 | 0 | 0 | 0
LED - BT Indicator |  |  | 5 | 0 | 0.1 | 1
LED – On Blink Indicator |  |  | 5 | 0 | 0.01 | 1
BT Module |  |  | 3.3 | 0.04 | 13 | 15 |  |  |  |  |  |  |  |  | expected/max are while transfering. Min is assuming full deep sleep is set up (?)
Sensor Temp-Humidity |  |  | 5 | 0.05 |  | 1.5
Sensor Dust |  |  | 5 | 0 | 50 | 55
Fan Copol |  |  | 3.3 | 0 | 20 | 20
SUM
Values after Boost/Buck

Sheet: Part Locations
USB CONNECTOR
 |  |  | VUSB | D- | D+ |  | UGND
 |  | Ptl | p1 | p2 | p3 | p4 | p5 | Ptr
 |  | Htl |  |  |  |  |  | Htr
 |  | Pbl2 |  |  |  |  |  | Pbr2
 |  | Pbl |  | BP bl |  | BP br |  | Pbr
 |  | Hbl |  |  |  |  |  | Hbr
 |  |  |  | All connectors connected to std gnd (not ugnd)
 | in mm
 | BP br | Hbr | Pbr | Pbr2 | Htr | Ptr | p5 | p4 | p3
x
y |  | 0 |  |  | 3.03 | 3.03
height | 2.5 | 1.2 |  |  | 1.05 |  | 1.75
width |  |  |  |  | 0.65 | 2 | 0.4
via diam
via 1y
via 2y
UDFN
Pitch = | 0.5 |  | W pad = | 0.3
H (tot) = | 3 |  | H pad = | 0.65
W (tot) = | 2 |  | Ac H =
 | x | y

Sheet: Calculations
Voltage Regulator RT6150 |  |  |  |  |  |  | LED's
VFB = | 0.5 |  |  |  |  |  | I = | 2
Voltage (wanted) | R1 (kohms) |  | R2 (calc) | R2 (actual | V (actual) |  | V led = | 2.2
3.3 | 487 |  |  | 86.6 |  |  | R (3.3) =
5 | 487 |  |  | 53.6 |  |  | R (5) =
Vin(max) = | 4.2
Vin(min) = | 2.9
switching f = | 1
Vout | Max Load | delta I load | Cout | L (uH) (buck min) | L (uH) (boost min) | delta Vout buck @Vmax | delta Vout buck @Vmin | delta Vout boost @Vmax | delta Vout boost @Vmin
3.3 |  | 0.4 | 20
5 | 1000 | 0.4 | 20
Voltage Regulator MC34673
Ichrg = | 0.6
Rset =
Rset (act) = | 6650
Ichrg (act) =
3.7

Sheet: Sheet4
Manufacturer ID | Manufactuerer | VID | Link | Name | Value | Pad | Height (mm)
AtMega32U4 | Atmel |  | http://www.mouser.com/ProductDetail/Atmel/ATMEGA32U4-MU/?qs=sGAEpiMZZMvAvBNgSS9LqtMxt75eRjif | Microcontroller | 16MHz
67997-206HLF | FCI |  | http://www.digikey.com/product-detail/en/67997-206HLF/609-3234-ND/1878491 | Connector ISP |  | .1''
ECS | ECS-160-20-3X-TR |  | http://www.digikey.com/product-detail/en/ECS-160-20-3X-TR/XC1776CT-ND/2676640 | Crystal | 16MHz – 20pF
CL10C200JB8NNNC | Samsung |  | http://www.digikey.com/product-detail/en/CL10C200JB8NNNC/1276-1187-1-ND/3889273 | Capacitor | 20pF | 0603
RC0603FR-071ML | Yageo |  | http://www.digikey.com/product-detail/en/RC0603FR-071ML/311-1.00MHRCT-ND/729791 | Resistor | 1M | 603
RC0603JR-0710KL | Yageo |  | http://www.digikey.com/product-detail/en/RC0603JR-0710KL/311-10KGRCT-ND/729647 | Resistor | 10k | 603
 |  |  | http://www.digikey.com/product-detail/en/550-1307F/350-1627-ND/809025 | LED – Green
 |  |  |  | LED - BT Indicator
 |  |  |  | LED – On Blink Indicator
n/a |  |  |  | BT Module
n/a |  |  | http://www.ebay.com/itm/NEW-DHT22-AM2302-Digital-Temperature-Humidity-Sensor-Replace-SHT11-SHT15-Logger-/271175728425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 | Sensor Temp-Humidity
n/a |  |  |  | Sensor Dust
F16FB-05LLC /E | Copol |  | http://www.digikey.com/product-search/en?vendor=0&keywords=copal+blower | Fan Copol
S4B-EH |  |  | http://www.digikey.com/product-detail/en/S4B-EH/455-1030-ND/527254 | Connector (Dust Sensor)
609-4050-2-ND |  |  |  | Connector USB Micro
LC2259EENP | E-Switch |  | http://www.futureelectronics.com/en/Technologies/Product.aspx?ProductID=LC2259EENPESWITCH6265227&IM=0 | Power Button | 300mA
 |  |  | http://www.jayconsystems.com/3-7-volt-rechargeable-lithium-battery-2000-mah.html | Battery – Lion | 2000mAH
LTC3530EMS#PBF | Linear Technology |  | http://www.digikey.com/product-detail/en/LTC3530EMS%23PBF/LTC3530EMS%23PBF-ND/1620105 | Voltage Reg Buck-Boost | 1.8-5V
LM2622MM-ADJ/NOPB | Texas Instruments |  | http://www.digikey.com/product-detail/en/LM2622MM-ADJ%2FNOPB/LM2622MM-ADJ%2FNOPBCT-ND/355386 | Voltage Reg Boost | 5V
LP2980AIM5-3.3/NOPB | Texas Instruments |  | http://www.digikey.com/product-detail/en/LP2980AIM5-3.3%2FNOPB/LP2980AIM5-3.3%2FNOPBCT-ND/334990 | Voltage Reg LDO | 3.3
MCP73831T-2ACI/OT | Miocrochip |  | http://www.digikey.com/product-detail/en/MCP73831T-2ACI%2FOT/MCP73831T-2ACI%2FOTCT-ND/1979802 | Volteage Reg USB
 |  |  | http://www.digikey.com/product-detail/en/NR6045T100M/587-2081-1-ND/1789028 | Inductor | 10uH |  | 4.5
 |  |  | http://www.digikey.com/product-detail/en/NR3015T1R5N/587-2617-1-ND/2349988 | Inductor | 1.5uH |  | 1.5
 |  |  | http://www.digikey.com/product-detail/en/BRL3225T2R2M/587-2165-1-ND/2002863 | Inductor | 2.2uH | 1210 | 1.7
 |  |  | http://www.digikey.com/product-detail/en/NRS5020T6R8MMGJ/587-2408-1-ND/2230274 | Inductor | 6uH |  | 2
 |  |  | http://www.digikey.com/product-detail/en/ERJ-3EKF8662V/P86.6KHCT-ND/198534 | Resistor | 86.6k | 0603
ERJ-3EKF4873V | Panasonic |  | http://www.digikey.com/product-detail/en/ERJ-3EKF4873V/P487KHCT-ND/198411 | Resistor | 487k | 0603
RT9819C-26GV | Richtek |  | http://www.digikey.com/product-detail/en/RT9819C-26GV/1028-1022-1-ND/2470081 | Low Voltage Detect | 2.6
MF-MSMF050-2 | Bourns Inc. |  | http://www.digikey.com/product-detail/en/MF-MSMF050-2/MF-MSMF050-2CT-ND/662842 | Fuse Resetable | 500mA
IRLML2246TRPBF | International Rectifier |  | http://www.digikey.com/product-detail/en/IRLML2246TRPBF/IRLML2246TRPBFCT-ND/2639576 | MOSFET–P |  |  | 1.2
B130LAW-7-F | Diodes Incorporated |  | http://www.digikey.com/product-detail/en/B130LAW-7-F/B130LAW-FDICT-ND/725052 | Diode Schottkey
MH2029-300Y | Bourns Inc. |  | http://www.digikey.com/product-detail/en/MH2029-300Y/MH2029-300YCT-ND/3741761 | Ferite Bead
CG0603MLC-05E | Bourns Inc. |  | http://www.digikey.com/product-detail/en/CG0603MLC-05E/CG0603MLC-05ECT-ND/3438061 | Varistor
RC0603JR-0722RL | Yageo |  | http://www.digikey.com/product-detail/en/RC0603JR-0722RL/311-22GRCT-ND/729690 | Resistor | 22
RC0603JR-0722RL | Yageo |  | http://www.digikey.com/product-detail/en/RC0603JR-070RL/311-0.0GRCT-ND/729622 | Resistor | 0 | 0603
C2012X5R1C106K085AC | TDK |  | http://www.digikey.com/product-detail/en/C2012X5R1C106K085AC/445-7644-1-ND/2733716 | Capacitor | 10uF | 0805
C1608X7R1E104K080AA | TDK |  | http://www.digikey.com/product-detail/en/C1608X7R1E104K080AA/445-1316-1-ND/567697 | Capacitor | 0.1uF | 0603
RC0603JR-0722RL | Yageo |  | http://www.digikey.com/product-detail/en/RC0603JR-0722RL/311-22GRCT-ND/729690 | Resistor | 22 | 0603
NDS331N | Fairchild |  | http://www.digikey.com/product-detail/en/NDS331N/NDS331NCT-ND/458997 | MOSFET – N
 |  |  |  | SUM
 |  |  |  | Values after Boost/Buck

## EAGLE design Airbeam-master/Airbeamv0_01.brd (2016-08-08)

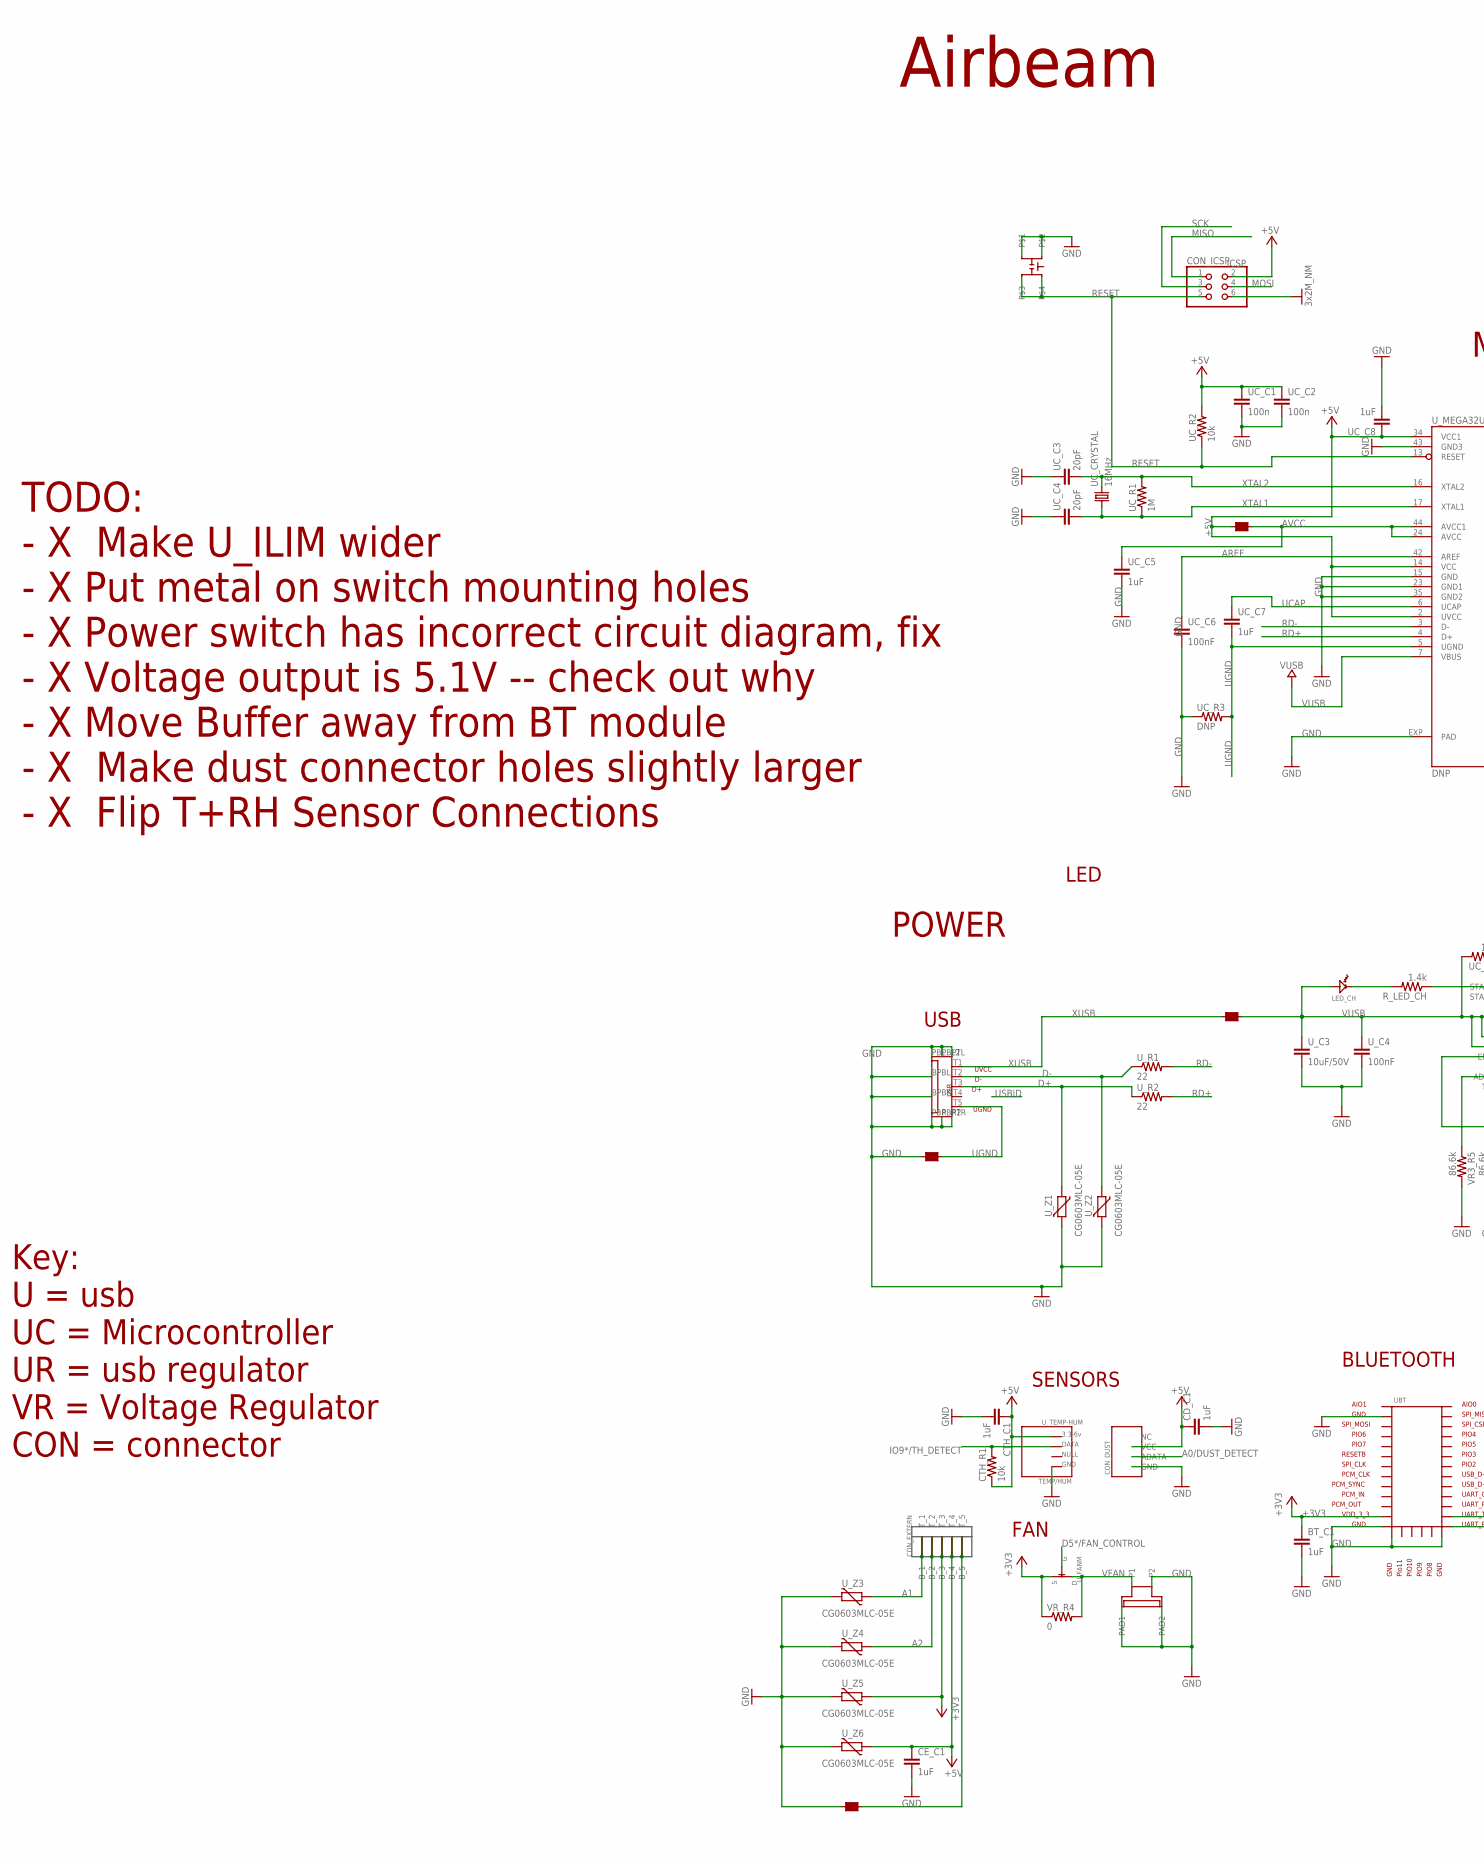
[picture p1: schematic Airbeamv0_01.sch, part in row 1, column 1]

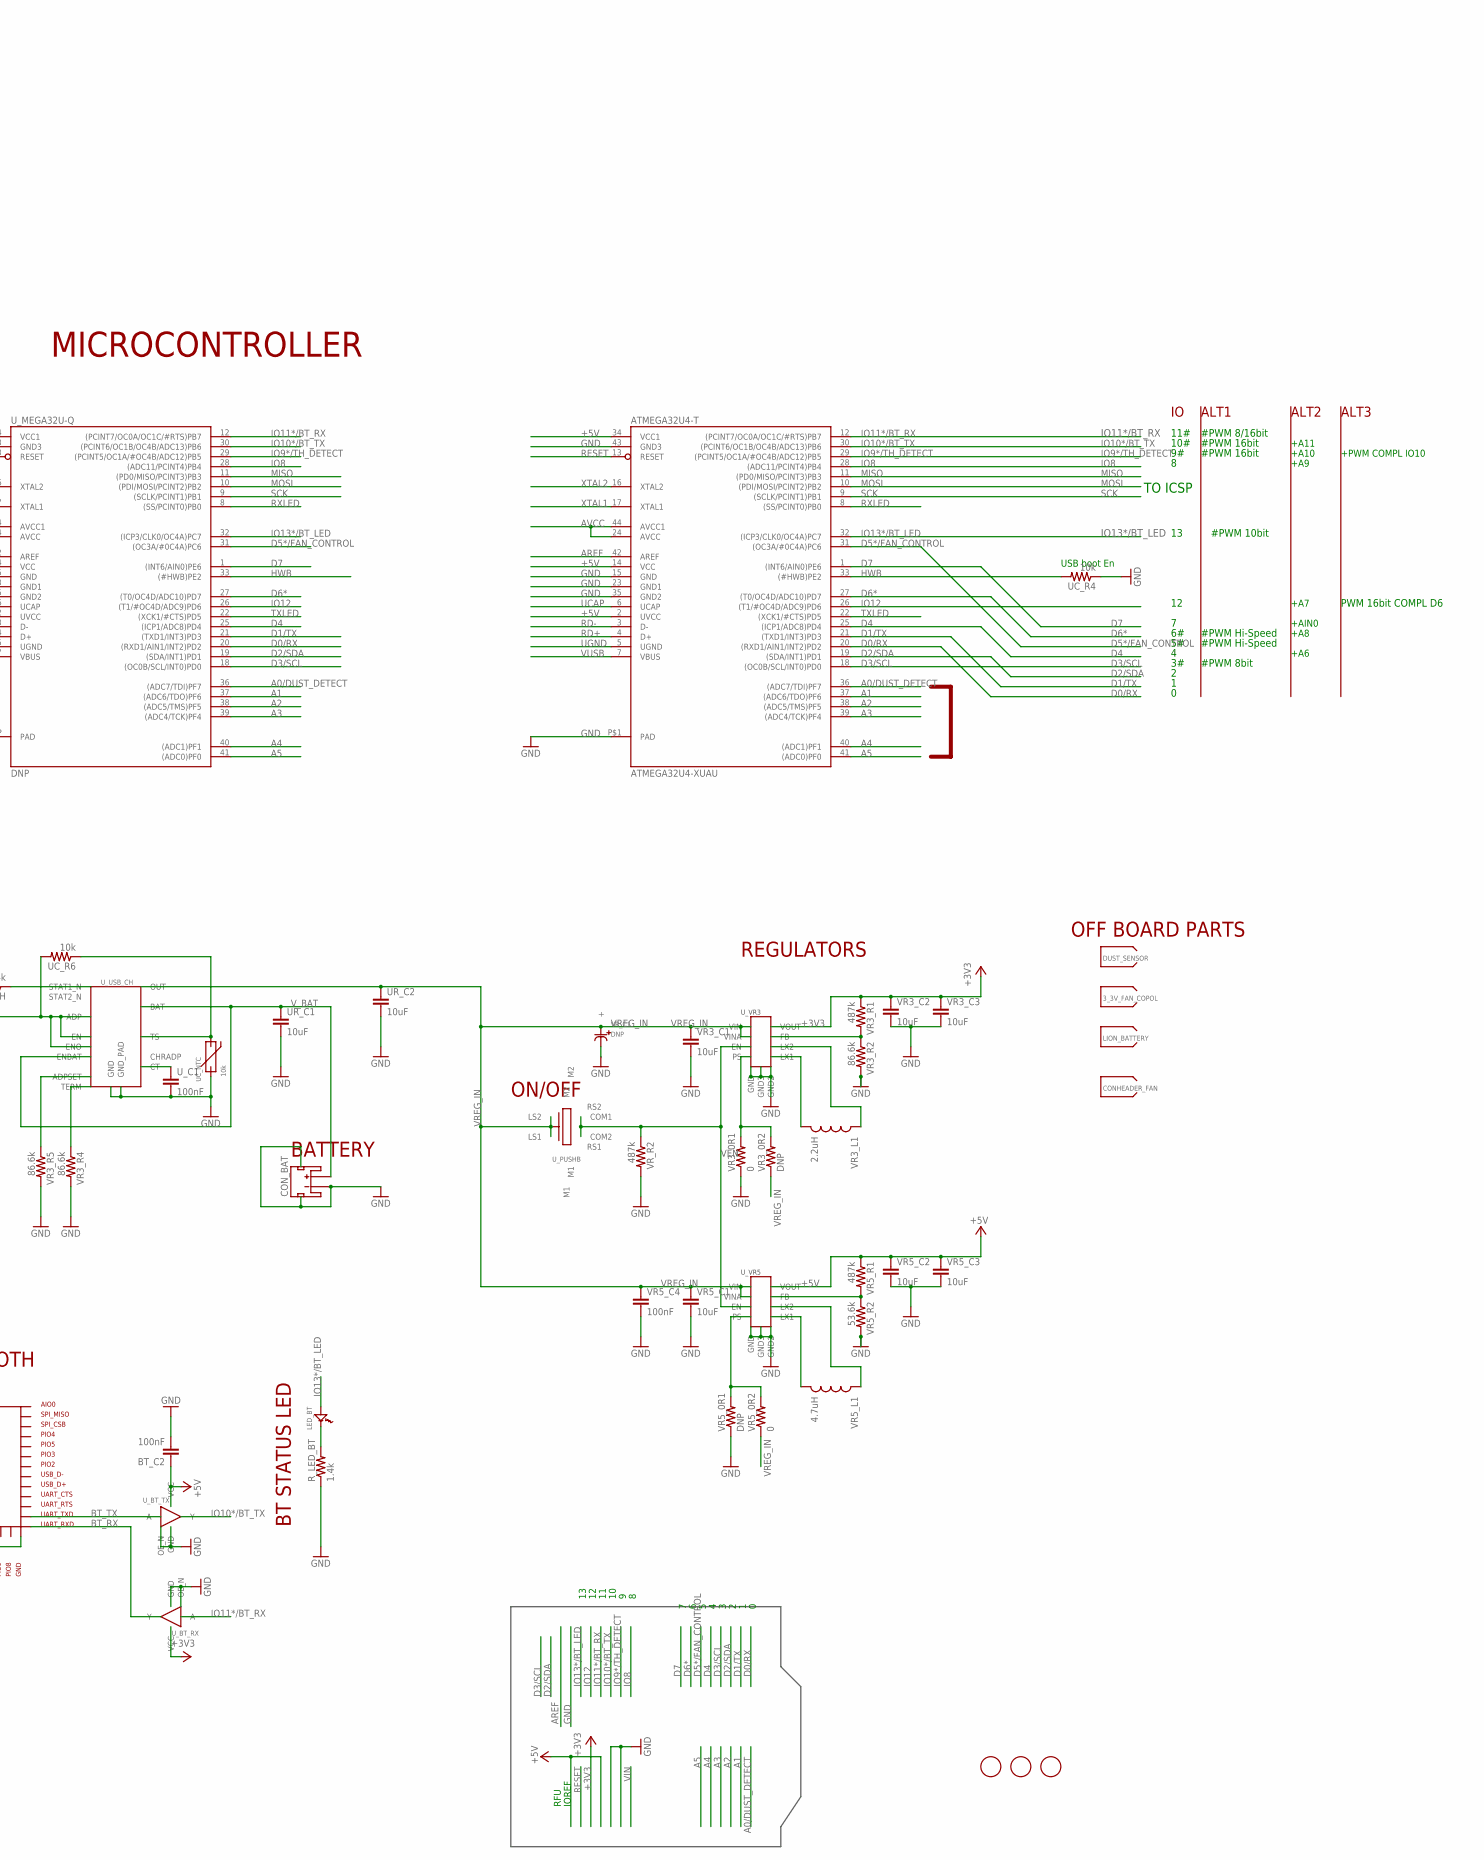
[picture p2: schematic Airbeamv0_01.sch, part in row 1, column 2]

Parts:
3_3V_FAN_COPOL: OFF_BOARD; EMPTY; PARTNO F16FB-05LLC/E
ATMEGA32U4-T: ATMEGA32U4-XUAU; TQFP44-PAD; PARTNO ATMEGA32U4-AU
BT_C1: 1uF; 0603-CAP; PARTNO C1608X5R1C105K080AA
BT_C2: 100nF; 0603-CAP; PARTNO C1608X7R1E104K080AA
CA_FB1: FERITE_BEAD; U_FB1; PARTNO MH2029-600Y
CD_C1: 1uF; 0603-CAP; PARTNO C1608X5R1C105K080AA
CE_C1: 1uF; 0603-CAP; PARTNO C1608X5R1C105K080AA
CONHEADER_FAN: OFF_BOARD; EMPTY; PARTNO 02SUR-32S
CON_BAT: CON_BAT; JST-2-SMD; PARTNO S2B-PH-SM4-TB(LF)(SN)
CON_DUST: CON_DUST; S4B-EH; PARTNO S4B-EH
CON_EXTERN: TBLOCK_5; PARTNO 1770911
CON_FAN: SUR_2PIN; JST-0.8MM
CON_ICSP: ICSP; 2X03; PARTNO 67997-206HLF
CON_USB: USB-FCI
CTH_C1: 1uF; 0603-CAP; PARTNO C1608X5R1C105K080AA
CTH_R1: 10k; 0603-RES; PARTNO RC0603JR-0710KL
DUST_SENSOR: OFF_BOARD; EMPTY; PARTNO PPD60PV-T2
FID1, FID2, FID3: FIDUCIALMOUNT; FIDUCIA-MOUNT; PARTNO DNP
LED_BT: LED; LED_550; PARTNO 550-1107F
LED_CH: LED; LED_550; PARTNO 550-1307F
LION_BATTERY: OFF_BOARD; EMPTY; PARTNO 585460_2000mAh
RESET_SWITCH: DNP; SWITCH_TACTILE
R_LED_BT: 1.4k; 0603-RES; PARTNO RC0603FR-071K4L
R_LED_CH: 1.4k; 0603-RES; PARTNO RC0603FR-071K4L
UBT: BT-NVC-MDCS42A; BT_NVC-MDCS42A
UC_C1, UC_C2: 100n; 0603-CAP; PARTNO C1608X7R1E104K080AA
UC_C3, UC_C4: 20pF; 0603-CAP; PARTNO CL10C200JB8NNNC
UC_C5, UC_C7, UC_C8: 1uF; 0603-CAP; PARTNO C1608X5R1C105K080AA
UC_C6: 100nF; 0603-CAP; PARTNO C1608X7R1E104K080AA
UC_CRYSTAL: 16MHz; HC49UP; PARTNO ECS-160-20-3X-TR
UC_NTC: 10k; 0402; PARTNO ERT-J0EM103J
UC_R1: 1M; 0603-RES; PARTNO RC0603FR-071ML
UC_R2, UC_R4, UC_R6: 10k; 0603-RES; PARTNO RC0603JR-0710KL
UC_R3: DNP; 0603-RES; PARTNO RC0603JR-070RL
UR_C1, UR_C2: 10uF; 0805; PARTNO C2012X5R1C106K085AC
U_BT_RX: V_BUFFER; SOT23-5
U_BT_TX: V_BUFFER; SOT23-5
U_C1: 100nF; 0603-CAP; PARTNO C1608X7R1E104K080AA
U_C3: 10uF/50V; 1206; PARTNO CL31A106KBHNNNE
U_C4: 100nF; 0603-CAP; PARTNO CC0603ZRY5V9BB104
U_FANM: DNP; SOT23
U_FB1, U_FB2, U_FB3: FERITE_BEAD; U_FB1; PARTNO MH2029-600Y
U_MEGA32U-Q: DNP; QFN44ML7X7; PARTNO ATMEGA32U4-MU
U_PUSHB: PUSHBUTTON
U_R1, U_R2: 22; 0603-RES; PARTNO RC0603JR-0722RL
U_TEMP-HUM: RHT03
U_USB_CH: USB-BATTERY_LOAD; TDFN33-14; PARTNO AAT3672IWO-4.2-1-T1
U_VR3, U_VR5: VREG-RTEC6150; WFDFN-10
U_Z1, U_Z2, U_Z3, U_Z4, U_Z5, U_Z6: CG0603MLC-05E; CT/CN0603; PARTNO CG0603MLC-05E
VR3_0R1, VR5_0R2: 0; 0603-RES; PARTNO RC0603JR-070RL
VR3_0R2, VR5_0R1: DNP; 0603-RES; PARTNO RC0603JR-070RL
VR3_C1, VR3_C2, VR3_C3, VR5_C1, VR5_C2, VR5_C3: 10uF; 0805; PARTNO C2012X5R1C106K085AC
VR3_L1: 2.2uH; 1210; PARTNO BRL3225T2R2M
VR3_R1, VR5_R1: 487k; 0603-RES; PARTNO ERJ-3EKF4873V
VR3_R2, VR3_R4, VR3_R5: 86.6k; 0603-RES; PARTNO ERJ-3EKF8662V
VR5_C4: 100nF; 0603-CAP; PARTNO C1608X7R1E104K080AA
VR5_L1: 4.7uH; 1210; PARTNO CBC3225T4R7MR
VR5_R2: 53.6k; 0603-RES; PARTNO RC0805FR-0753K6L
VR_C1: DNP; 2917_CAP
VR_R2: 487k; 0603-RES; PARTNO ERJ-3EKF4873V
VR_R4: 0; 0603-RES; PARTNO RC0603JR-070RL

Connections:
+3V3: BT_C1.1, CON_EXTERN.B_3, CON_EXTERN.T_3, UBT.P$12, U_BT_RX.5 (VCC), U_FANM.2, U_VR3.P$1 (VOUT), U_Z5.1, VR3_C2.1, VR3_C3.1, VR3_R1.1, VR_R4.1
+5V: ATMEGA32U4-T.2 (UVCC), ATMEGA32U4-T.14 (VCC), ATMEGA32U4-T.34 (VCC1), BT_C2.1, CD_C1.1, CE_C1.1, CON_DUST.P$3 (VCC), CON_EXTERN.B_4, CON_EXTERN.T_4, CON_ICSP.2, CTH_C1.1, CTH_R1.1, UC_C1.1, UC_C2.1, UC_C8.1, UC_R2.2, U_BT_TX.5 (VCC), U_FB2.P$1, U_MEGA32U-Q.2 (UVCC), U_MEGA32U-Q.14 (VCC), U_MEGA32U-Q.34 (VCC1), U_TEMP-HUM.P$1, U_VR5.P$1 (VOUT), U_Z6.1, VR5_C2.1, VR5_C3.1, VR5_R1.1
A0/DUST_DETECT: ATMEGA32U4-T.36 ((ADC7/TDI)PF7), CON_DUST.P$2 (ADATA), U_MEGA32U-Q.36 ((ADC7/TDI)PF7)
A1: ATMEGA32U4-T.37 ((ADC6/TDO)PF6), CON_EXTERN.B_1, CON_EXTERN.T_1, U_MEGA32U-Q.37 ((ADC6/TDO)PF6), U_Z3.1
A2: ATMEGA32U4-T.38 ((ADC5/TMS)PF5), CON_EXTERN.B_2, CON_EXTERN.T_2, U_MEGA32U-Q.38 ((ADC5/TMS)PF5), U_Z4.1
A3: ATMEGA32U4-T.39 ((ADC4/TCK)PF4), U_MEGA32U-Q.39 ((ADC4/TCK)PF4)
A4: ATMEGA32U4-T.40 ((ADC1)PF1), U_MEGA32U-Q.40 ((ADC1)PF1)
A5: ATMEGA32U4-T.41 ((ADC0)PF0), U_MEGA32U-Q.41 ((ADC0)PF0)
AREF: ATMEGA32U4-T.42 (AREF), UC_C6.1, U_MEGA32U-Q.42 (AREF)
AVCC: ATMEGA32U4-T.24 (AVCC), ATMEGA32U4-T.44 (AVCC1), UC_C5.1, U_FB2.P$2, U_MEGA32U-Q.24 (AVCC), U_MEGA32U-Q.44 (AVCC1)
BT_RX: UBT.P$20, U_BT_RX.4 (Y)
BT_TX: UBT.P$21, U_BT_TX.2 (A)
D0/RX: ATMEGA32U4-T.20 ((RXD1/AIN1/INT2)PD2), U_MEGA32U-Q.20 ((RXD1/AIN1/INT2)PD2)
D1/TX: ATMEGA32U4-T.21 ((TXD1/INT3)PD3), U_MEGA32U-Q.21 ((TXD1/INT3)PD3)
D2/SDA: ATMEGA32U4-T.19 ((SDA/INT1)PD1), U_MEGA32U-Q.19 ((SDA/INT1)PD1)
D3/SCL: ATMEGA32U4-T.18 ((OC0B/SCL/INT0)PD0), U_MEGA32U-Q.18 ((OC0B/SCL/INT0)PD0)
D4: ATMEGA32U4-T.25 ((ICP1/ADC8)PD4), U_MEGA32U-Q.25 ((ICP1/ADC8)PD4)
D5*/FAN_CONTROL: ATMEGA32U4-T.31 ((OC3A/#0C4A)PC6), U_FANM.1, U_MEGA32U-Q.31 ((OC3A/#0C4A)PC6)
D6*: ATMEGA32U4-T.27 ((T0/OC4D/ADC10)PD7), U_MEGA32U-Q.27 ((T0/OC4D/ADC10)PD7)
D7: ATMEGA32U4-T.1 ((INT6/AIN0)PE6), U_MEGA32U-Q.1 ((INT6/AIN0)PE6)
D+: CON_USB.T3, U_R2.1, U_Z1.1
D-: CON_USB.T2, U_R1.1, U_Z2.1
GND: ATMEGA32U4-T.15 (GND), ATMEGA32U4-T.23 (GND1), ATMEGA32U4-T.35 (GND2), ATMEGA32U4-T.43 (GND3), ATMEGA32U4-T.P$1 (PAD), BT_C1.2, BT_C2.2, CA_FB1.P$1, CD_C1.2, CE_C1.2, CON_BAT.1 (-), CON_BAT.NC1 (PAD1), CON_BAT.NC2 (PAD2), CON_DUST.P$1 (GND), CON_FAN.P2, CON_FAN.PAD1, CON_FAN.PAD2, CON_ICSP.6, CON_USB.BPBL, CON_USB.BPBR, CON_USB.PBL, CON_USB.PBL2, CON_USB.PBR, CON_USB.PBR2, CON_USB.PTL, CON_USB.PTR, CTH_C1.2, RESET_SWITCH.P1, RESET_SWITCH.P2, R_LED_BT.1, UBT.P$2, UBT.P$13, UBT.P$14, UBT.P$19, UC_C1.2, UC_C2.2, UC_C3.1, UC_C4.1, UC_C5.2, UC_C6.2, UC_C8.2, UC_NTC.1, UC_R3.1, UC_R4.1, UR_C1.2, UR_C2.2, U_BT_RX.1 (OE_N), U_BT_RX.3 (GND), U_BT_TX.1 (OE_N), U_BT_TX.3 (GND), U_C1.2, U_C3.2, U_C4.2, U_FB1.P$1, U_MEGA32U-Q.15 (GND), U_MEGA32U-Q.23 (GND1), U_MEGA32U-Q.35 (GND2), U_MEGA32U-Q.43 (GND3), U_MEGA32U-Q.EXP (PAD), U_TEMP-HUM.P$4, U_USB_CH.GND_PAD, U_USB_CH.P$4 (GND), U_VR3.MID_PAD (GND3), U_VR3.P$3 (GND), U_VR3.P$9 (GND2), U_VR5.MID_PAD (GND3), U_VR5.P$3 (GND), U_VR5.P$9 (GND2), U_Z1.2, U_Z2.2, U_Z3.2, U_Z4.2, U_Z5.2, U_Z6.2, VR3_0R1.1, VR3_C1.2, VR3_C2.2, VR3_C3.2, VR3_R2.2, VR3_R4.2, VR3_R5.2, VR5_0R1.1, VR5_C1.2, VR5_C2.2, VR5_C3.2, VR5_C4.2, VR5_R2.2, VR_C1.T- (-), VR_R2.2
HWB: ATMEGA32U4-T.33 ((#HWB)PE2), UC_R4.2, U_MEGA32U-Q.33 ((#HWB)PE2)
IO8: ATMEGA32U4-T.28 ((ADC11/PCINT4)PB4), U_MEGA32U-Q.28 ((ADC11/PCINT4)PB4)
IO9*/TH_DETECT: ATMEGA32U4-T.29 ((PCINT5/OC1A/#OC4B/ADC12)PB5), CTH_R1.2, U_MEGA32U-Q.29 ((PCINT5/OC1A/#OC4B/ADC12)PB5), U_TEMP-HUM.P$2
IO10*/BT_TX: ATMEGA32U4-T.30 ((PCINT6/OC1B/OC4B/ADC13)PB6), U_BT_TX.4 (Y), U_MEGA32U-Q.30 ((PCINT6/OC1B/OC4B/ADC13)PB6)
IO11*/BT_RX: ATMEGA32U4-T.12 ((PCINT7/OC0A/OC1C/#RTS)PB7), U_BT_RX.2 (A), U_MEGA32U-Q.12 ((PCINT7/OC0A/OC1C/#RTS)PB7)
IO12: ATMEGA32U4-T.26 ((T1/#OC4D/ADC9)PD6), U_MEGA32U-Q.26 ((T1/#OC4D/ADC9)PD6)
IO13*/BT_LED: ATMEGA32U4-T.32 ((ICP3/CLK0/OC4A)PC7), LED_BT.ANODE (AN), U_MEGA32U-Q.32 ((ICP3/CLK0/OC4A)PC7)
MISO: ATMEGA32U4-T.11 ((PD0/MISO/PCINT3)PB3), CON_ICSP.1, U_MEGA32U-Q.11 ((PD0/MISO/PCINT3)PB3)
MOSI: ATMEGA32U4-T.10 ((PDI/MOSI/PCINT2)PB2), CON_ICSP.4, U_MEGA32U-Q.10 ((PDI/MOSI/PCINT2)PB2)
unnamed: U_VR3.P$2 (LX2), VR3_L1.1
unnamed: U_USB_CH.P$10 (TERM), VR3_R4.1
unnamed: LED_BT.CATHODE (CATH), R_LED_BT.2
unnamed: U_VR3.P$10 (FB), VR3_R1.2, VR3_R2.1
unnamed: UC_NTC.2, UC_R6.1, U_USB_CH.P$11 (TS)
unnamed: U_C1.1, U_USB_CH.P$14 (CT)
unnamed: CA_FB1.P$2, CON_EXTERN.B_5, CON_EXTERN.T_5
unnamed: R_LED_CH.1, U_USB_CH.P$3 (STAT1_N)
unnamed: U_VR3.P$4 (LX1), VR3_L1.2
unnamed: U_VR5.P$10 (FB), VR5_R1.2, VR5_R2.1
unnamed: U_VR5.P$2 (LX2), VR5_L1.1
unnamed: U_VR5.P$4 (LX1), VR5_L1.2
unnamed: LED_CH.CATHODE (CATH), R_LED_CH.2
unnamed: U_USB_CH.P$1 (ADPSET), VR3_R5.1
RD+: ATMEGA32U4-T.4 (D+), U_MEGA32U-Q.4 (D+), U_R2.2
RD-: ATMEGA32U4-T.3 (D-), U_MEGA32U-Q.3 (D-), U_R1.2
RESET: ATMEGA32U4-T.13 (RESET), CON_ICSP.5, RESET_SWITCH.P3, RESET_SWITCH.P4, UC_R2.1, U_MEGA32U-Q.13 (RESET)
RXLED: ATMEGA32U4-T.8 ((SS/PCINT0)PB0), U_MEGA32U-Q.8 ((SS/PCINT0)PB0)
SCK: ATMEGA32U4-T.9 ((SCLK/PCINT1)PB1), CON_ICSP.3, U_MEGA32U-Q.9 ((SCLK/PCINT1)PB1)
TXLED: ATMEGA32U4-T.22 ((XCK1/#CTS)PD5), U_MEGA32U-Q.22 ((XCK1/#CTS)PD5)
UCAP: ATMEGA32U4-T.6 (UCAP), UC_C7.1, U_MEGA32U-Q.6 (UCAP)
UGND: ATMEGA32U4-T.5 (UGND), CON_USB.T5, UC_C7.2, UC_R3.2, U_FB1.P$2, U_MEGA32U-Q.5 (UGND)
VEN: U_PUSHB.C1 (COM1), U_PUSHB.C2 (COM2), U_VR3.P$6 (EN), U_VR5.P$6 (EN), VR_R2.1
VFAN: CON_FAN.P1, U_FANM.3, VR_R4.2
VR3_PS: U_VR3.P$7 (PS), VR3_0R1.2, VR3_0R2.2
VR5_PS: U_VR5.P$7 (PS), VR5_0R1.2, VR5_0R2.2
VREG_IN: UR_C2.1, U_PUSHB.LS1, U_PUSHB.LS2, U_USB_CH.P$13 (OUT), U_VR3.P$5 (VIN), U_VR3.P$8 (VINA), U_VR5.P$5 (VIN), U_VR5.P$8 (VINA), VR3_0R2.1, VR3_C1.1, VR5_0R2.1, VR5_C1.1, VR5_C4.1, VR_C1.T+ (+)
VUSB: ATMEGA32U4-T.7 (VBUS), LED_CH.ANODE (AN), UC_R6.2, U_C3.1, U_C4.1, U_FB3.P$2, U_MEGA32U-Q.7 (VBUS), U_USB_CH.P$2 (ADP), U_USB_CH.P$6 (EN), U_USB_CH.P$7 (ENO)
V_BAT: CON_BAT.2 (+), UR_C1.1, U_USB_CH.P$8 (ENBAT), U_USB_CH.P$12 (BAT)
XTAL1: ATMEGA32U4-T.17 (XTAL1), UC_C4.2, UC_CRYSTAL.1, UC_R1.1, U_MEGA32U-Q.17 (XTAL1)
XTAL2: ATMEGA32U4-T.16 (XTAL2), UC_C3.2, UC_CRYSTAL.2, UC_R1.2, U_MEGA32U-Q.16 (XTAL2)
XUSB: CON_USB.T1, U_FB3.P$1

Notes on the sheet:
Airbeam
USB boot En
USB
TO ICSP
10#
11#
#PWM 8bit
#PWM Hi-Speed
#PWM 8/16bit
#PWM 16bit
PWM 16bit COMPL D6
#PWM 10bit
+A6
+A7
+A11
+A10
+A8
+A9
+PWM COMPL IO10
+AIN0
ALT1
ALT2
ALT3
SENSORS
TODO: - X Make U_ILIM wider - X Put metal on switch mounting holes - X Power switch has incorrect circuit diagram, fix - X Voltage output is 5.1V -- check out why - X Move Buffer away from BT module - X Make dust connector holes slightly larger - X Flip T+RH Sensor Connections
BATTERY
POWER
Key: U = usb UC = Microcontroller UR = usb regulator VR = Voltage Regulator CON = connector
REGULATORS
ON/OFF
BLUETOOTH
MICROCONTROLLER
FAN
BT STATUS LED
LED
IOREF
RFU
OFF BOARD PARTS

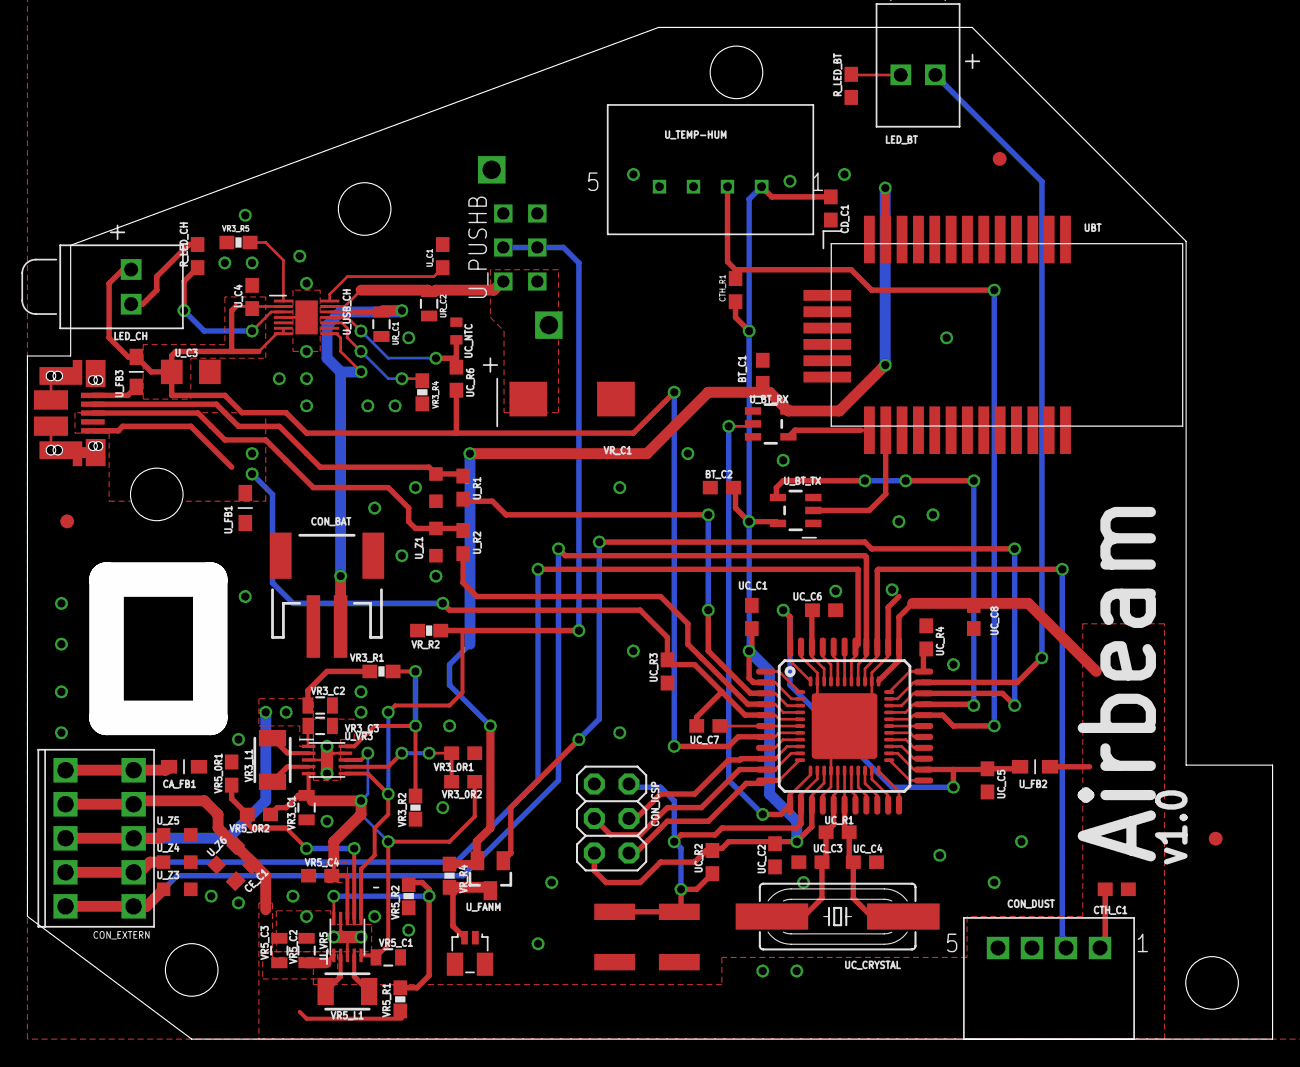
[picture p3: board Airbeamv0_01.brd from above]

Board: 2 copper layers, 91.4 x 74.3 mm, 90 parts (0 on the bottom side), 64 nets.

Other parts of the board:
U$6: EAGLE_FREESPACE

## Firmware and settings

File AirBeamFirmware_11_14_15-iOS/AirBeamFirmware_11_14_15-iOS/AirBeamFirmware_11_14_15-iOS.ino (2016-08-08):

// AIRBEAM Firmware version 11/14/15
// Modified to communicate with RN4020 BTLE module for iOS use

// ORIGINAL: original source: AirCastingAndroidClient/arduino/aircasting/AirBeamFirmware_11_14_15
// MODIFIED: 07/19/2016 Nick Masson nicholas.b.masson@gmail.com

/*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
    You should have received a copy of the GNU Affero General Public License
    along with this program.  If not, see <http://www.gnu.org/licenses/>.
*/
//=======================================================================

#include <SoftwareSerial.h>
#include <DHT.h>
#include <stdlib.h>

#define DHTPIN 9
#define DHTTYPE DHT22   // DHT 22  (AM2302)

int humi, cel, fah, kelv; 
unsigned long analogcount;
double analogtotal;

String inData;
unsigned long duration;
unsigned long starttime = 0;
unsigned long sampletime_ms = 1000;
unsigned long analogvalue = 0;
double hppcf = 0;
double ugm3 = 0;

DHT dht(DHTPIN, DHTTYPE);
SoftwareSerial mySerial(10, 11); //RX, TX

#define LEDPIN 13
#define BT_BUF_LEN 10
char bt_index = 0;
char bt_buffer[BT_BUF_LEN];
int8_t bt_connected = -1; // 0 = not connected (but been connected), 1 == connected, -1 == never been connected

uint8_t put_chr_buf(char c){
  // puts a character into the bt_buffer.
  // If the character is '\n' returns 1 (and doesn't put it into the buffer)
  // else returns 0
  if(c == '\n'){
      return 1;
  }
  if(bt_index >= BT_BUF_LEN - 2){
    return 0;
  }
  bt_buffer[bt_index] = c;
  bt_index++;
  bt_buffer[bt_index] = 0;
  return 0;
}

void analyze_buf(){
  // Determines if the buffer contains the SS notation
  if(bt_connected == -1){
    if(strncmp(bt_buffer, "SS=", 3) == 0){
      bt_connected = 0;
      Serial.println(F("1st Connect to BT"));
    }
  }
  else{
    if(strncmp(bt_buffer, "OK", 2) == 0){
    }
    else{
      Serial.println(F("ERROR: Unknown response:"));
      Serial.println(bt_buffer);
    }
    bt_connected = 0;
  }
  bt_buffer[0] = 0;
  bt_index = 0;
}

void update_bt_status(){
  // This should be called in the loop with at least a hundred milliescond delay before it is called again.
  // Determine if the BT module is connected or not.
  uint8_t temp = 0;
  if(mySerial.available()){
    while(mySerial.available()){
      temp = put_chr_buf(mySerial.read());
      if(temp){
        analyze_buf();
      }
    }
  }
  else{
    if(bt_connected >= 0){
      bt_connected = 1;
    }
  }
  
  // clear excess
  while(mySerial.available()){
    mySerial.read();
  }
  
  // Send out another signal for the next loop
  mySerial.println(F("BC:UI=01"));
  
  // Indicate connection status via the LED
  digitalWrite(LEDPIN, HIGH);
  if(bt_connected < 1){
    delay(100);
    digitalWrite(LEDPIN, LOW);
    delay(100);
  }
}

String readBTMAC() {
inData = "";
if (mySerial.available() > 0) {
Serial.println(mySerial.available());
int h = mySerial.available();
for (int i = 0; i < h; i++) {
inData += (char)mySerial.read();
}
inData.remove(23 ,24);
inData.remove(0, 11);
}
return inData;
}

void clear_bt_serial(){
  while(mySerial.available()){
    Serial.write(mySerial.read());
  }
}

void setup() {
  pinMode(LEDPIN, OUTPUT);
  digitalWrite(LEDPIN, HIGH);
  delay(2000);
  Serial.begin(115200);
  mySerial.begin(115200);
  //mySerial.println("BC:BR=08");
  mySerial.println("S-,AirBeam");
  //delay(100);
  delay(500);
  
  /*mySerial.begin(19200);
  mySerial.println("BC:BR=08");
  delay(100);
  
  mySerial.begin(9600);
  mySerial.println("BC:BR=08");
  delay(100);
  
  mySerial.begin(19200);
  */
  //mySerial.println("BC:FT=00,00,00,01,03,0000");  // It will never try to autoconnect and will always be in discoverable mode.
  //delay(100);
  mySerial.println("SR,30000800");
  delay(500);
  //mySerial.println(("BC:AD"));
  //delay(100);
  //readBTMAC();
  mySerial.println("R,1");
  delay(2000);

  mySerial.println("D");
  delay(500);
  
  //mySerial.print(("BC:NM=AirBeam-"));
  //mySerial.println(inData);
  //bt_buffer[0] = 0;
  starttime = millis();
}

void loop() {
  digitalWrite(LEDPIN,HIGH);
  delay(5000);
  analogvalue = analogvalue + analogRead(0);
  analogcount++;

  humi = dht.readHumidity();
  cel = dht.readTemperature();
  fah = ((cel * 9)/5) + 32;
 
  //update_bt_status();
  if ((millis()-starttime) > sampletime_ms)
  {
    starttime = millis(); // moved to create more regular periods.
    analogvalue = analogvalue/analogcount;
    analogtotal = (analogvalue*5.0)/1024;
    hppcf = (240.0*pow(analogtotal,6) - 2491.3*pow(analogtotal,5) + 9448.7*pow(analogtotal,4) - 14840.0*pow(analogtotal,3) + 10684.0*pow(analogtotal,2) + 2211.8*(analogtotal) + 7.9623);
    ugm3 = .518 + .00274 * hppcf;
    if(ugm3 < 0){
      ugm3 = 0;
    }
     
    Serial.println();
  //  Serial.print("AirBeam MAC: ");
  //  Serial.print(inData);
    Serial.print(" ");
    Serial.print(fah);
    Serial.print(F("F "));
    Serial.print(cel);
    Serial.print(F("C "));
    Serial.print(humi);
    Serial.print(F("RH "));
    Serial.print(F(" Analog Total: "));
    Serial.print(analogtotal);
    Serial.print(F(" hppcf: "));
    Serial.print(hppcf);
    Serial.print(F(" ugm^3: "));
    Serial.print(ugm3);
    Serial.println();
    
    analogvalue = 0;
    analogcount = 0;
    //lowpulseoccupancy = 0;
    
   // if(bt_connected > 0){
      //mySerial.print(analogtotal);
      //mySerial.print((";AirBeam:"));
      //mySerial.print(inData);
      //mySerial.print((";AirBeam-PM-V;Particulate Matter;PM;Volts;V;0;1;2;3;4"));
      //mySerial.print("\n");
      
      //mySerial.print(hppcf);
      //mySerial.print((";AirBeam:"));
      //mySerial.print(inData);
      //mySerial.print((";AirBeam-PM-hppcf;Particulate Matter;PM;hundreds of particles per cubic foot;hppcf;0;3000;8000;13000;26000"));
      //mySerial.print("\n");
      
      mySerial.print(ugm3);
    //  mySerial.print((";AirBeam:"));
    //  mySerial.print(inData);
    //  mySerial.print((";AirBeam-PM;Particulate Matter;PM;micrograms per cubic meter;µg/m³;0;12;35;55;150"));
    //  mySerial.print("\n");
      mySerial.print(",");
      
      mySerial.print(fah);
    //  mySerial.print((";AirBeam:"));
     // mySerial.print(inData);
     // mySerial.print((";AirBeam-F;Temperature;F;degrees Fahrenheit;F;0;25;50;75;100"));
     // mySerial.print("\n");
      mySerial.print(",");
   
      //mySerial.print(cel);
      //mySerial.print((";AirBeam:"));
      //mySerial.print(inData);
      //mySerial.print((";AirBeam-C;Temperature;C;degrees Celsius;C;0;10;20;30;40"));
      //mySerial.print("\n");
      
      mySerial.print(humi);
    //  mySerial.print((";AirBeam:"));
     // mySerial.print(inData);
     // mySerial.print((";AirBeam-RH;Humidity;RH;percent;%;0;25;50;75;100"));
     // mySerial.print("\n");
      mySerial.print(",");
      mySerial.print("\n");
      
   // }
    }
}

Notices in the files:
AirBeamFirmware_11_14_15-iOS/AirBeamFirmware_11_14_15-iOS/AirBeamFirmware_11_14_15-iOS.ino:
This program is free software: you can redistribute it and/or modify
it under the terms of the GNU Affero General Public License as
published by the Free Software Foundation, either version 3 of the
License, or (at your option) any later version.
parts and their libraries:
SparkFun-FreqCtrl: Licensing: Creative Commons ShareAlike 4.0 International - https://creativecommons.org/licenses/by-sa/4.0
